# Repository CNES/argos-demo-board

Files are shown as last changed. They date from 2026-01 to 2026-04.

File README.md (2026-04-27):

# Argos Demo Board Using Arribada SMD Module

Demonstration and evaluation board designed to operate the **Arribada Argos SMD module** via USB and transmit **ARGOS uplink messages to the Kineis satellite constellation**.

---

> *© 2025/2026 CNES – Paul Miailhe.*  
> *This material is licensed under the CERN Open Hardware Licence Version 2 (CERN-OHL-S).*  
> *See licence: https://ohwr.org/licences/* 

> 
> 
> 
> 
> 
> 
---

<p align="center">
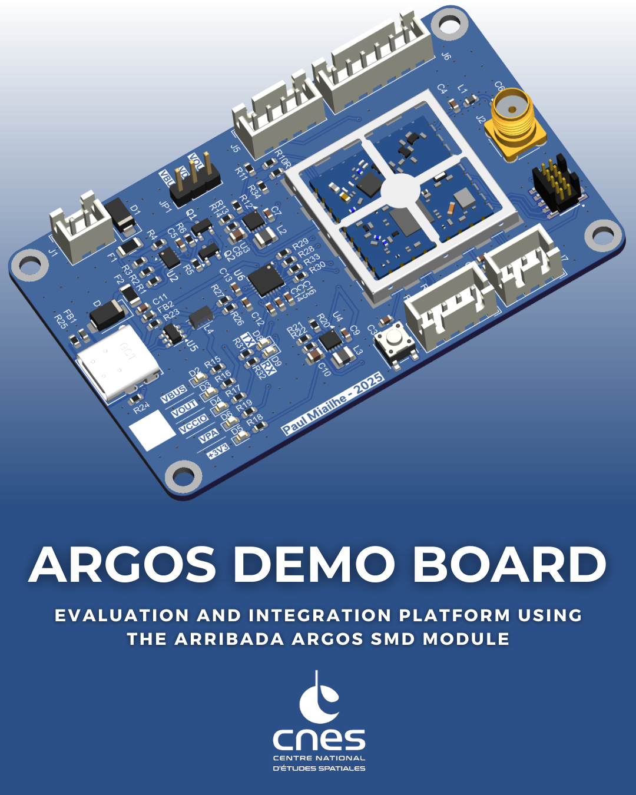
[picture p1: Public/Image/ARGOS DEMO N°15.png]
Argos Demonstration Board
  
</p>

---

## Introduction

This project presents an **Argos Transceiver Demonstration Board** intended for the evaluation, validation, and operation of the **Arribada Argos SMD module**.  
The board provides a compact and robust hardware platform to transmit **ARGOS uplink messages to the Kineis satellite constellation** using a standard **USB interface**.

Communication between the host computer and the Arribada SMD module is handled by a **FTDI FT231XQ USB-to-UART bridge**, directly interfacing with the module UART. This approach enables simple control of the transceiver using standard serial terminals or custom software tools.

The demonstration board integrates all essential functions required to operate the Arribada SMD module in a laboratory or development environment, including power supply conditioning, USB-to-UART communication, and RF interfacing. It is primarily intended to support early hardware validation, firmware development, and system-level testing of Argos communication chains prior to integration into a final embedded or avionics system.

This board targets engineers, students, and developers involved in **satellite communications, avionics, IoT, or space-related applications**, and may be used both as a standalone evaluation platform and as a reference hardware design.

---

> Inline with Arribada's open source philosophy, this board deliberately adopts a design distinct from the official demonstration hardware, focusing on simplicity and direct plug-and-play operation from a standard PC. The schematic and architecture are provided for reference, allowing potential users to reuse, adapt, or extend them according to their own needs..

---

## Hardware Design

<p align="center">
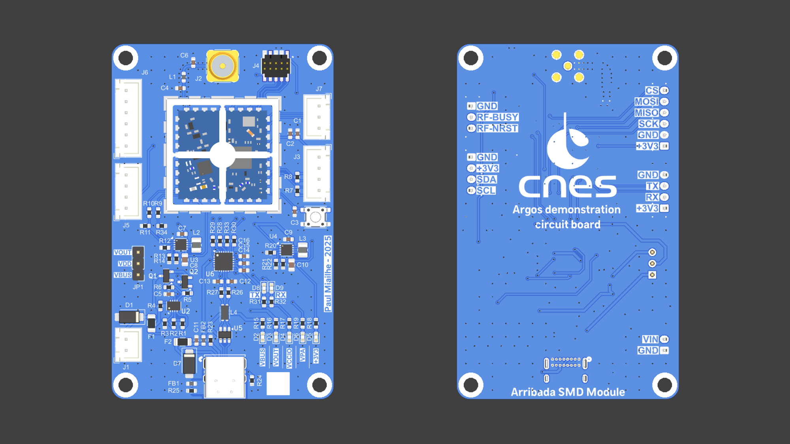
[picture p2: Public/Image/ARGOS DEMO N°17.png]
Top and bottom
  
</p>

### 1. Communication Architecture

Communication between the host PC and the **Arribada Argos SMD module** is performed through the module’s **UART interface**.  
This interface is used to send **AT commands** from a PC in order to configure the module and transmit **ARGOS uplink messages**. 
[→ See details on GitHub Arribada](https://github.com/arribada/argos-smd-at-kineis-firmware)

The USB-to-UART conversion is handled by a **FTDI FT231XQ USB 2.0 to UART bridge**. This device converts USB data received from a **virtual COM port** into UART signals fully compatible with the Arribada SMD module.

This architecture allows the board to be operated using:
- Standard serial terminal software
- Custom scripts
- Dedicated test or validation tools

No additional embedded controller is required, which simplifies early testing and debugging.

---

### 2. Power Supply Architecture

The card supports two power supply modes to suit different uses.

#### 2.1 Power Source Selection

Power source selection is performed using the **JP1 jumper**, which allows switching between:
- **VBUS → VDD (5V)** supplied by the **USB-C port**
- **VOUT → VDD (5V)** supplied via the **external power input on connector J1**

#### 2.2 External Power Protection

The external power input on **connector J1** is protected by:
- A **resettable PTC fuse 1206L050YR**
- A **LTC4365 protection circuit**

The **LTC4365** provides:
- **Reverse polarity protection**
- **Undervoltage protection** with a threshold set to **2.5 V**
- **Overvoltage protection** for input voltages exceeding **5 V**

#### 2.3 Power Regulation

After the protection stage, the power rail is distributed to two **TPS63900 buck-boost converters**:
- One converter supplies the **RF power amplifier (PA)** and is **enabled and controlled directly by the Arribada SMD module**
- The second converter is **always enabled** and provides the regulated **3.3 V supply** required for the **Arribada SMD module logic**

---

### 3. Connector Types

The Argos Demo Board uses the following connector families:

- **USB4085-GF-A (GCT)**  
  **USB Type-C receptacle (16-pin)** used for:
  - USB 2.0 communication with the host PC
  - Board power supply via **VBUS**

- **JST B2B-XH series**  
  **Through-hole wire-to-board connectors** used for:
  - External power input (**2.5 V to 5 V**)
  - Digital interfaces (**UART, SPI, GPIO – 3.3 V logic**)
  - General-purpose I/O connections

- **FTSH-105-01-L-DV-K (Samtec)**  
  **10-pin JTAG connector** used for:
  - Programming
  - Low-level debugging of the **Arribada Argos SMD module**
  - Access to **JTAG/SWD signals** of the embedded **STM32WL55**

- **60312002114503 (Würth Elektronik)**  
  **SMA 50 Ω RF connector** used for:
  - RF output connection
  - External antenna interface for the **ARGOS frequency band**
  - ⚠️ When transmitting, it is important to have at least a 50 Ohm load connected to the antenna output to protect against impedance mismatch. 

---

### 4. Functional Diagram

<p align="center">
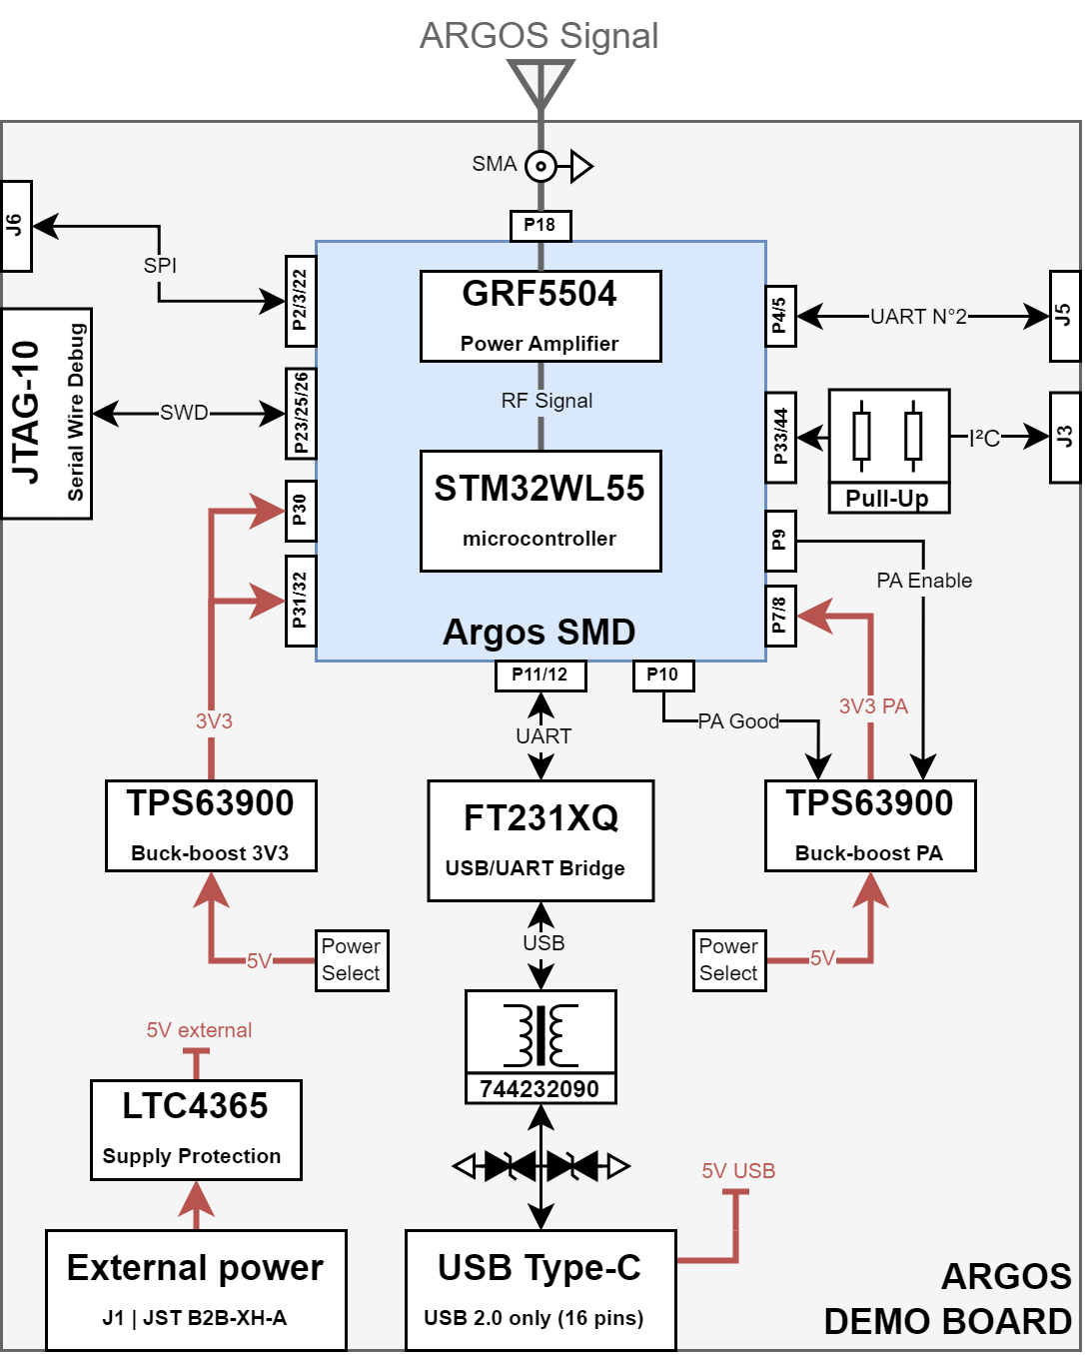
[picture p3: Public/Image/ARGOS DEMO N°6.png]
Argos Demonstration Board – Functional Diagram
  
</p>

---
## Summary of the Bill of Materials (BOM) 

  
Components used on the board, with their official datasheets:

| Reference | Part Number | Role / Function | Datasheet |
|---|---|---|---|
| D1, D7 | SMAJ15CA | TVS diode for surge and ESD protection | [→ Datasheet Littelfuse](https://www.littelfuse.com/assetdocs/tvs-diodes-smaj-datasheet?assetguid=13c2a823-03b8-4d1f-9ddc-9b44670aed9d) |
| F1, F2 | 1206L035/16YR | Resettable PTC fuse (overcurrent protection) | [→ Datasheet Littelfuse](https://www.littelfuse.com/assetdocs/resettable-ptcs-1206l-datasheet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) |
| FB1, FB2 | BLM18KG601SN1D | Ferrite bead for EMI suppression | [→ Datasheet Murata](https://pim.murata.com/en-eu/pim/details/?partNum=BLM18KG601SN1%23) |
| L4 | 744232090 | Common-mode choke for USB line filtering | [→ Datasheet Würth Elektronik](https://www.we-online.com/components/products/datasheet/744232090.pdf) |
| Q1, Q2 | BSN20 | N-channel MOSFET for switching and protection | [→ Datasheet DIODES INC.](http://www.diodes.com/assets/Datasheets/ds31898.pdf) |
| SW1 | PTS647 | Momentary tactile push button switch | [→ Datasheet C&K](https://www.ckswitches.com/media/1471/pts647.pdf) |
| U2 | LTC4365DDB | Overvoltage, undervoltage and reverse polarity protection IC | [→ Datasheet Analog Devices](https://www.analog.com/media/en/technical-documentation/data-sheets/4365fa.pdf) |
| U3, U4 | TPS63900 | Buck-boost DC/DC converters | [→ Datasheet Texas Instruments](https://www.ti.com/lit/ds/symlink/tps63900.pdf) |
| U5 | 82400102 | Low-capacitance TVS diode array for USB protection | [→ Datasheet Würth Elektronik](https://www.we-online.com/components/products/datasheet/82400102.pdf) |
| U6 | FT231XQ | USB-to-UART bridge | [→ Datasheet FTDI](https://www.ftdichip.com/Support/Documents/DataSheets/ICs/DS_FT231X.pdf) |
| H4 | 3610213126S | RF shielding cabinet | [→ Datasheet Würth Elektronik](https://www.we-online.com/catalog/datasheet/3610213126S.pdf) |
| J8 | USB4085-GF-A | USB 2.0-only 16P Type-C Receptacle connector | [→ Datasheet GCT](https://www.usb.org/sites/default/files/documents/usb_type-c.zip) |
| J2 | 60312002114503 | Coaxial connector SMA | [→ Datasheet Würth Elektronik](https://www.we-online.com/components/products/datasheet/60312002114503.pdf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) |
| J4 | FTSH-105-01-L-DV-K | JTAG 10-PINS | [→ Datasheet Samtec](https://suddendocs.samtec.com/catalog_english/ftsh_smt.pdf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) |
| J1, J3, J5, J6, J7 | B2B-XH | Through-hole wire-to-board connectors | [→ Datasheet JST](https://www.jst.fr/core/file.get?path=doc/jst/family/pdf/exh0125.pdf) |
| U1 | Argos SMD module | Transceiver Argos SMD for uplink Argos satellite | [→ Datasheet Arribada](https://github.com/arribada/featherwings-argos-smd-hw/wiki) |

---

## Getting Started

1. Connect the demonstration board to a host computer using a USB cable.
2. Install the **FTDI drivers** if required.
3. Select the desired **power input** using the **JP1 jumper**.
4. Connect an **antenna or a 50 Ω RF load** to the **SMA connector** before powering the board.
5. Open a **serial terminal** or a **custom software tool** on the host computer.
6. Configure the serial port according to the **Arribada Argos SMD module specifications**.
7. Send **AT commands** to configure the module and transmit **ARGOS uplink messages**.
8. If the board is operating correctly, the **5 V and 3.3 V LEDs** should be ON, and **TX/RX activity LEDs** should indicate serial communication.

Refer to the Arribada SMD module documentation for command syntax and operational details.

---

## Regulatory and Operational Notice

ARGOS transmissions are subject to regulatory constraints and operational authorization.

- Transmission over the ARGOS / Kineis constellation may require prior approval
- Users are responsible for ensuring compliance with applicable regulations
- This board does not grant any transmission rights by itself

---

## Mechanical Characteristics

- Dimensions: **80 × 50 mm**
- Maximum thickness: **13.5 mm**
- Mounting holes: 4 × Ø3.2 mm
- Weight without bracket: ** g**
- **STEP 3D** file available here:

<p align="center">
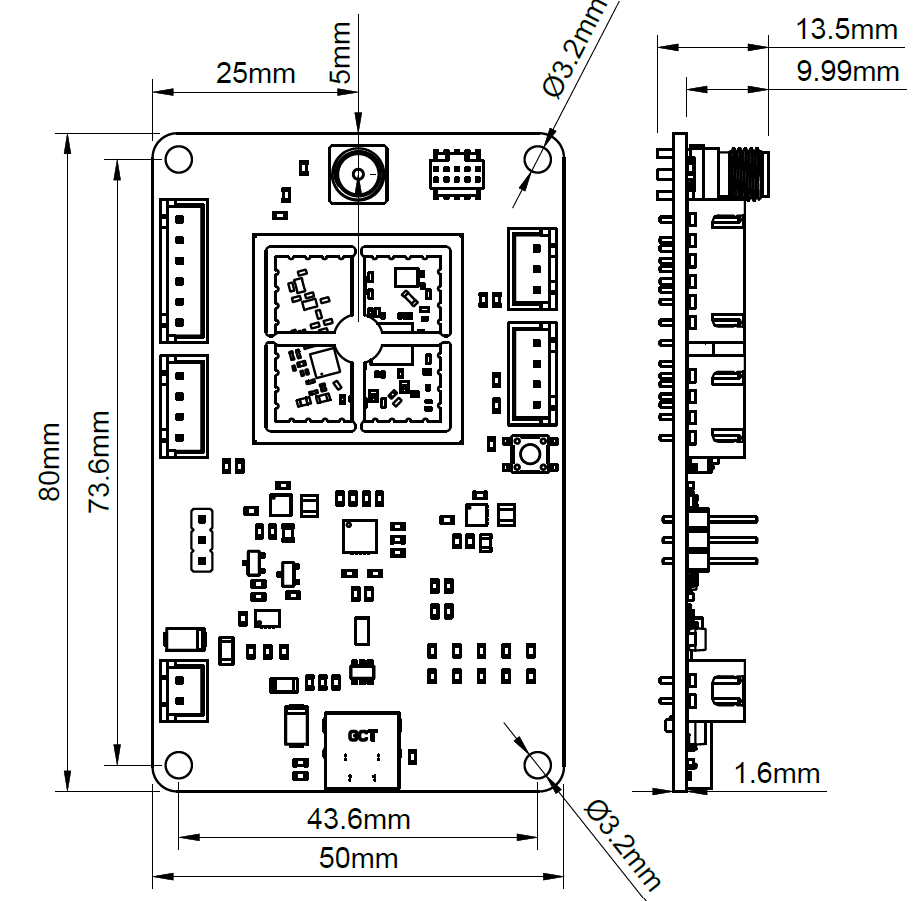
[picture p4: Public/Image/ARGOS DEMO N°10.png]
Argos Demonstration Board – Mechanical Characteristics
  
</p>

---

## Regulatory and Operational Notice

ARGOS transmissions are subject to regulatory and operational constraints.

- Transmission over the ARGOS / Kineis constellation require prior authorization
- Users are responsible for regulatory compliance
- This board does **not** grant transmission rights by itself

---

## References & Resources

- **Arribada Initiative** – Official site  
  See link: <https://arribada.org>

- **Official Argos SMD Arduino Demo** – by Arribada  
  The full Arduino-based demonstration for the Argos SMD module is available on GitHub.  
  See link: <https://github.com/arribada/argos-smd-test-arduino>

- **Official Breakout Board FeatherWings** – by Arribada  
  This breakout board can be used with a Feather board (from Adafruit) to connect the ARGOS-SMD module.  
  It exposes the ARGOS-SMD module pins to the Feather board and includes a dedicated LDO to power the RF amplifier.  
  See link: <https://github.com/arribada/featherwings-argos-smd-hw>

- **Official Argos SMD Hardware Module** – by Arribada  
  The Arribada Argos SMD module is a compact **20 × 20 mm PCB** designed to operate as a standalone module or co-processor, enabling satellite communication via the **Kineis network**.  
  See link: <https://github.com/arribada/argos-smd-hw>

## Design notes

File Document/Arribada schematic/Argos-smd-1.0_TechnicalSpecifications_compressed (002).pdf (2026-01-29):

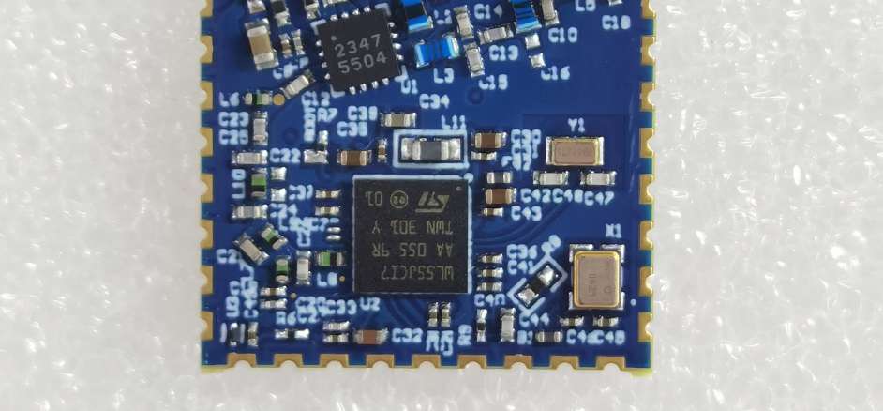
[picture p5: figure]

# SMD Module for Argos Communication

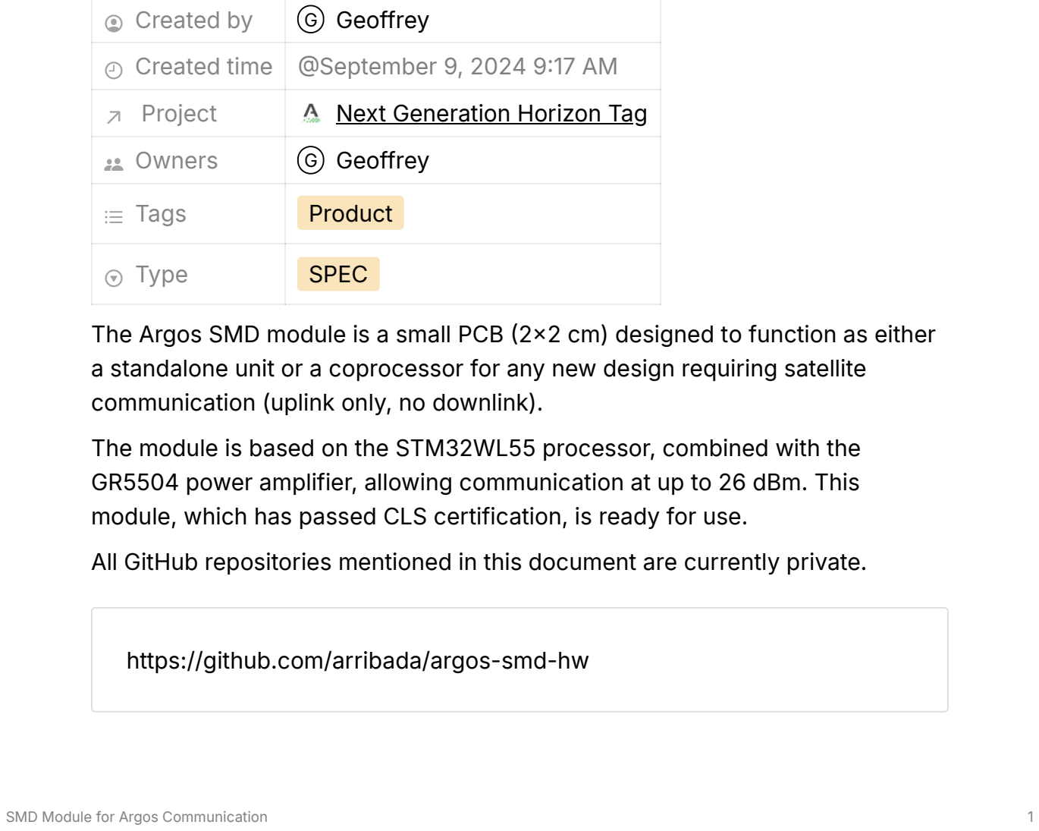
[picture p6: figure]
SMD Module for Argos Communication; Created by; G Geoffrey; Created time; Project; Next Generation Horizon Tag (https://www.notion.so/Next-Generation-Horizon-Tag-afd0edbfa5694a8ea1d60a53f880d056?pvs=21); Owners; Tags; Product; Type; SPEC; communication (uplink only, no downlink).; https://github.com/arribada/argos-smd-hw; September 9, 2024 9

The Argos SMD module is a small PCB (2x2 cm) designed to function as either a standalone unit or a coprocessor for any new design requiring satellite

The module is based on the STM32WL55 processor, combined with the GR5504 power amplifier, allowing communication at up to 26 dBm. This module, which has passed CLS certification, is ready for use.
All GitHub repositories mentioned in this document are currently private.

# 1. Size and Dimensions

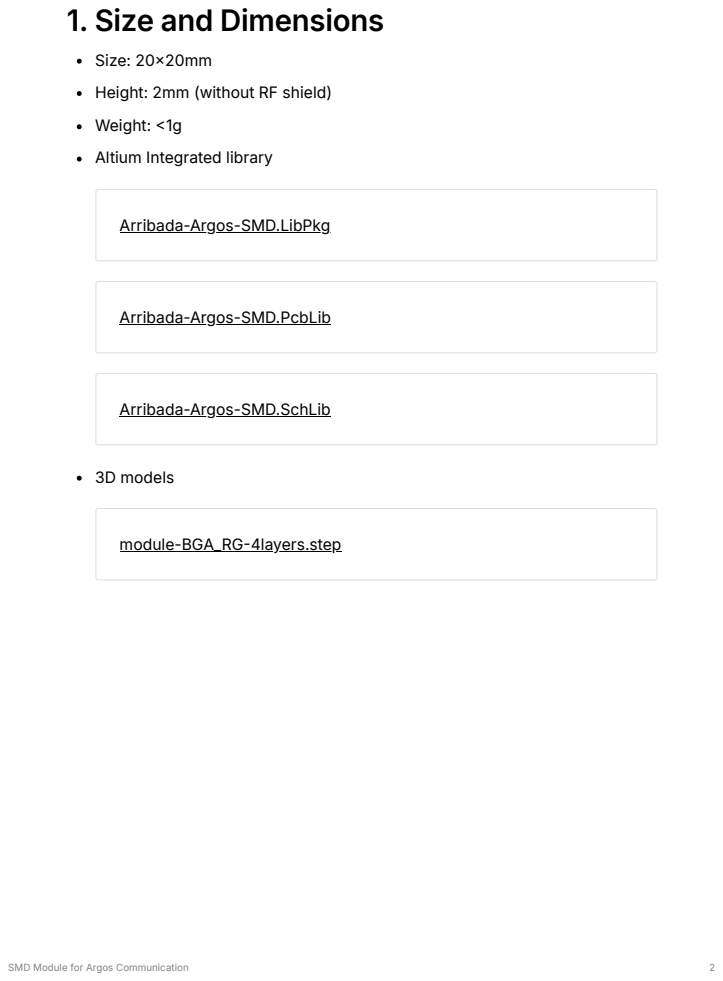
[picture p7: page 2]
3D models; module-BGA_RG-4layers.step

Size: 20x20mm
Height: 2mm (without RF shield)
Weight: <1g
Altium Integrated library

Arribada-Argos-SMD.LibPkg (https://www.notion.so/signed/https%3A%2F%2Fprod-files-secure.s3.us-west-2.amazonaws.com%2Ffb6dcbe8-5387-40b2-9784-804645a3e60e%2F554a35c8-f4b7-4a3d-868e-001f1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)

Arribada-Argos-SMD.PcbLib (https://www.notion.so/signed/https%3A%2F%2Fprod-files-secure.s3.us-west-2.amazonaws.com%2Ffb6dcbe8-5387-40b2-9784-804645a3e60e%2Fce79ae03-3859-4164-9c10-c49fd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)

Arribada-Argos-SMD.SchLib (https://www.notion.so/signed/https%3A%2F%2Fprod-files-secure.s3.us-west-2.amazonaws.com%2Ffb6dcbe8-5387-40b2-9784-804645a3e60e%2Ff151bbcf-b28b-4e5a-810b-bd9d2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)

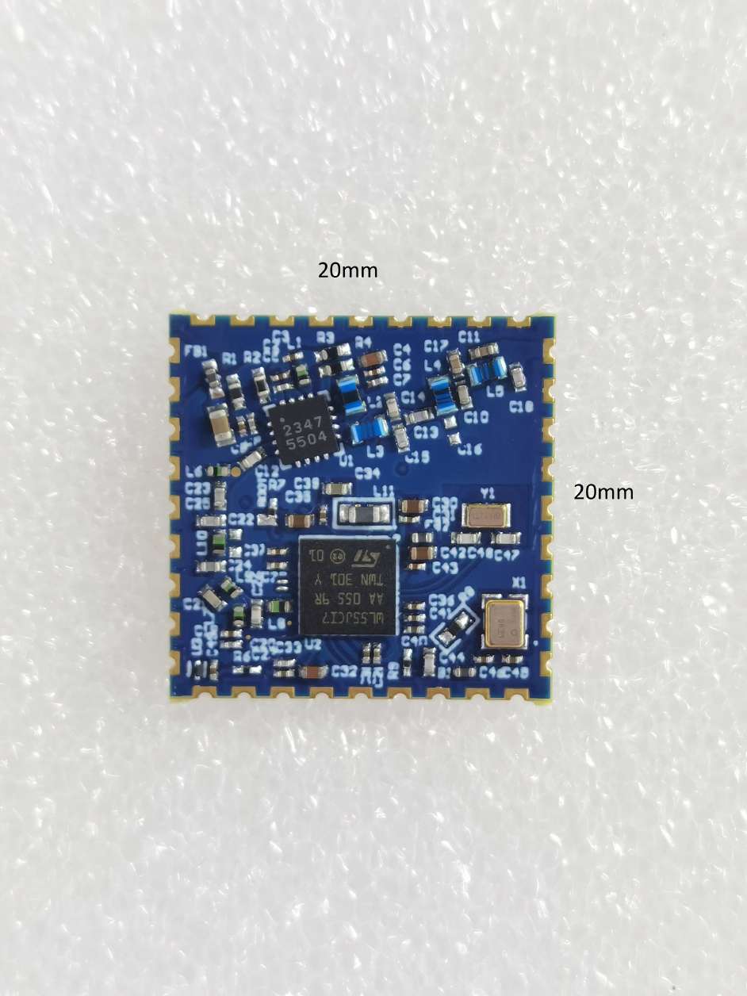
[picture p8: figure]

It’s possible to add an RF shield (https://www.mouser.fr/ProductDetail/Wurth-Elektronik/36903255S?qs=ECv811tYSNg3zTXFceofhw%3D%3D) on the board dedicated to integrated the SMD module with the following dimensions:

Size: 25x25mm

Height: 3.2mm

# 2. Integration

The module integration requires a power supply for the STM32 and a second one for the external power amplifier. A PI-filter should be added to the antenna output before connecting it to the antenna connector. The TPS63901 (https://www.ti.com/product/TPS63901) is recommended for powering the external PA.
A breakout board is available to test the module and provide a design integration example. This breakout board can be used with a Feather board (from Adafruit) to connect the ARGOS-SMD module. It exposes the ARGOS-SMD module pins to the Feather board and includes a dedicated LDO to power the RF amplifier. You can find resources at the following link.

# 3 - Power Supply Voltages

VDD (Core Supply Voltage):
1.8V to 3.6V operating range.

Typical operation at 3.3V.
VBAT (Battery Backup Supply):

Backup battery voltage range from 1.55V to 3.6V.

This is used to power the RTC (Real-Time Clock), backup registers, and some other low-power functionalities when the main supply is off. VDDPA (Power Amplifier Supply):

For the internal power amplifier (PA) dedicated to the radio subsystem. 1.8V to 3.6V supply voltage.

VDD_EXTPA (Power External Amplifier):

Typical operation at 3.3V.

Argos communication power consumption: TX power: 25.8dBm (380mW)

VPA: 3.40V
Power max: 292.40mA

Power mean: 165.13mA

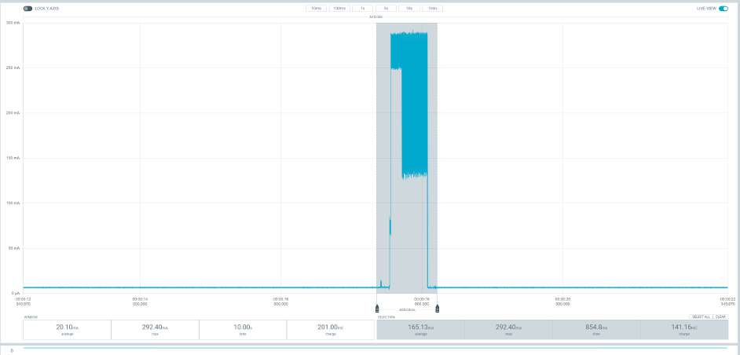
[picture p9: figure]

# 4. Pinout

The module features the following pinout configuration:
While it is possible to adapt the pinout definition through programming of the STM32 module, the following pinout has been selected.

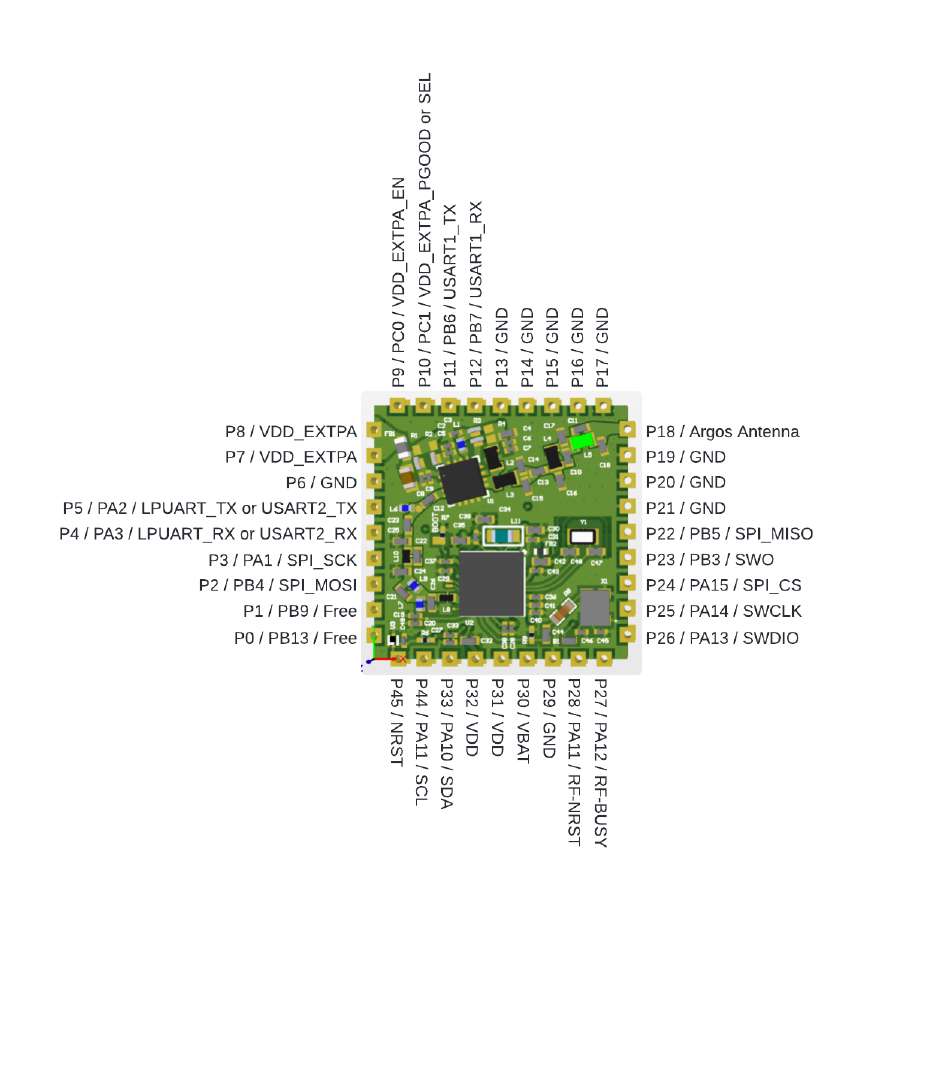
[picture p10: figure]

System:
P35 => nRST

P31 => VDD

P32 => VDD
P30 => VBAT

Power amplifier:
P7: VDD power amplifier

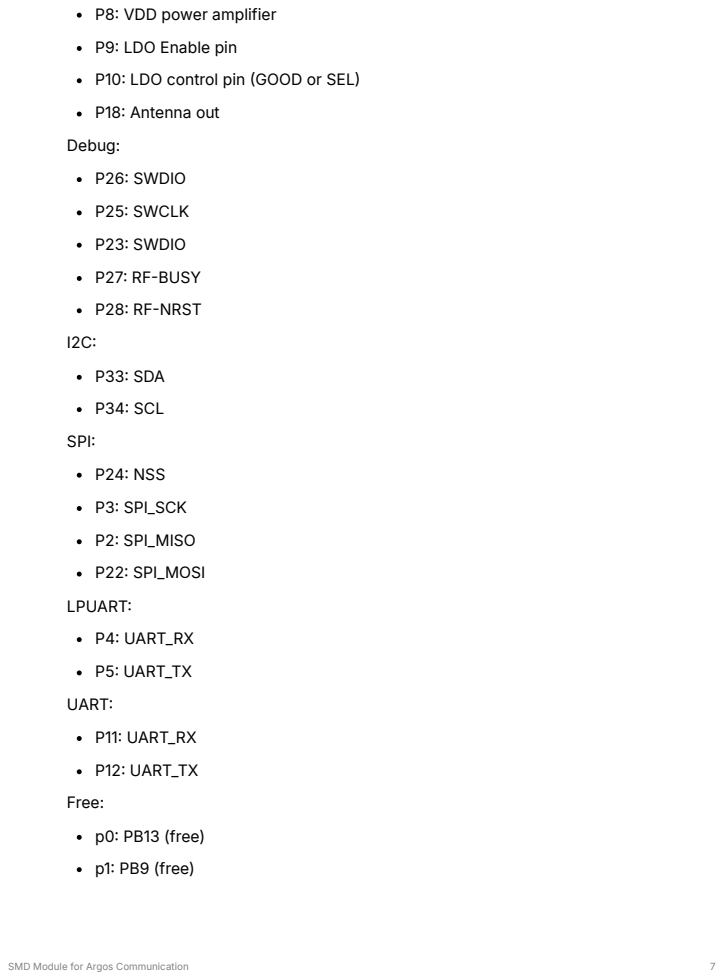
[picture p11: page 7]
P8: VDD power amplifier; P9: LDO Enable pin; P10: LDO control pin (GOOD or SEL); P18: Antenna out; Debug:; P26: SWDIO; P25: SWCLK; P23: SWDIO; P27: RF-BUSY; P28: RF-NRST; P33: SDA; P34: SCL; SPI:; P24: NSS; P3: SPI_SCK; P2: SPI_MISO; P22: SPI_MOSI; LPUART:; P4: UART_RX; P5: UART_TX; UART:; P11: UART_RX; P12: UART_TX; Free:; p0: PB13 (free); p1: PB9 (free)

# 4. Software

The firmware used for the module is based on the latest CLS firmware v6.2.1 and is available on the following GitHub repository.

https://github.com/arribada/SMD-AT-Kineis
The Kineis stack requires credentials (ID, address, secret key) to run properly. The easiest way to test the module is to use the latest KimGUI interface provided by CLS. This computer application allows communication with the module via UART.
A Zephyr driver can also be used to communicate with the SMD module. For example, when combining the breakout board with an Adafruit Feather board, the following Zephyr driver can be used to test the module.

It is also possible to use the STM32 example for AT commands to control the Sub-GHz module at this link:

https://github.com/arribada/SMD_AT_Slave

## 4.1. Communication Protocol

The SMD module is configured to communicate via LPUART1 with the following parameters:
Baud Rate: 9600 bps

Data Bits: 8

Stop Bits: 1
Parity: None

Flow Control: None

## 4.2. Command Structure

An ID provides by CLS should be configured on the SMD module to allows communication (28 or 32bits ID).
The SMD module use the same KimGUI AT command format, like this :

AT+[COMMAND]=[PARAMETER]

Example commands:
"AT+PING=?\r\n to get information

"AT+TX=<user_data>\r\n to set information

List of commands:

{ "AT+VERSION", | 10, bMGR_AT_CMD_VERSION_cmd},
{ "AT+PING", | 7, bMGR_AT_CMD_PING_cmd},
{ "AT+FW", | 5, bMGR_AT_CMD_FW_cmd},
{ "AT+ADDR", | 7, bMGR_AT_CMD_ADDR_cmd},
{ "AT+ID", | 5, bMGR_AT_CMD_ID_cmd},
{ "AT+SN", | 5, bMGR_AT_CMD_SN_cmd},
{ "AT+RCONF", | 8, bMGR_AT_CMD_RCONF_cmd},
{ "AT+SAVE_RCONF", | 13, bMGR_AT_CMD_SAVE_RCONF_cmd},
{ "AT+LPM", | 6, bMGR_AT_CMD_LPM_cmd},
{ "AT+TX", | 5, bMGR_AT_CMD_TX_cmd},
{ "AT+CW", | 5, bMGR_AT_CMD_CW_cmd},
{ "AT+PREPASS_EN", | 13, bMGR_AT_CMD_PREPASS_EN_cmd},
{ "AT+UDATE", | 8, bMGR_AT_CMD_UDATE_cmd},
{ "AT+ATXRP", | 8, bMGR_AT_CMD_ATXRP_cmd},

# 5. Environmental Specifications

The hardware components used in this design have been selected to meet rigorous environmental requirements, ensuring reliable operation in a wide range of conditions. The key specifications are as follows:
1. Operating Temperature Range:

The components are capable of operating in temperatures ranging from 40°C to +85°C.

2. Storage Temperature:
The hardware can be safely stored in environments with temperatures between 55°C and +150°C.
3. Humidity Resistance:
Operation in environments with up to 85% to 95% relative humidity
4. Moisture Sensitivity:

All components are Moisture Sensitivity Level (MSL 1).
5. RoHS Compliance:

All components are RoHS compliant.
This hardware design leverages industry-standard components, known for their reliability and performance in demanding environments, making it ideal for robust applications such as satellite communication systems.

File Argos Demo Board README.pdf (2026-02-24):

README.md | 2026-01-30

# Argos Demo Board Using Arribada SMD Module

Demonstration and evaluation board designed to operate the Arribada Argos SMD module via USB and transmit ARGOS uplink messages to the Kineis satellite constellation.

© 2025/2026 CNES – Paul Miailhe.
This material is licensed under the CERN Open Hardware Licence Version 2 (CERN-OHL-S). See licence: https://ohwr.org/licences/


## Introduction

This project presents an Argos Transceiver Demonstration Board intended for the evaluation, validation, and operation of the Arribada Argos SMD module.

The board provides a compact and robust hardware platform to transmit ARGOS uplink messages to the Kineis satellite constellation using a standard USB interface.

Communication between the host computer and the Arribada SMD module is handled by a FTDI FT231XQ USB-to-UART bridge, directly interfacing with the module UART. This approach enables simple control of the transceiver using standard serial terminals or custom software tools.

The demonstration board integrates all essential functions required to operate the Arribada SMD module in a laboratory or development environment, including power supply conditioning, USB-to-UART communication, and RF interfacing. It is primarily intended to support early hardware validation, firmware development, and system-level testing of Argos communication chains prior to integration into a final embedded or avionics system.

This board targets engineers, students, and developers involved in satellite communications, avionics, IoT, or space-related applications, and may be used both as a standalone evaluation platform and as a reference hardware design.

Inline with Arribada's open source philosophy, this board deliberately adopts a design distinct from the official demonstration hardware, focusing on simplicity and direct plug-and-play operation from a standard PC. The schematic and architecture are provided for reference, allowing potential users to reuse, adapt, or extend them according to their own needs..

## Hardware Design

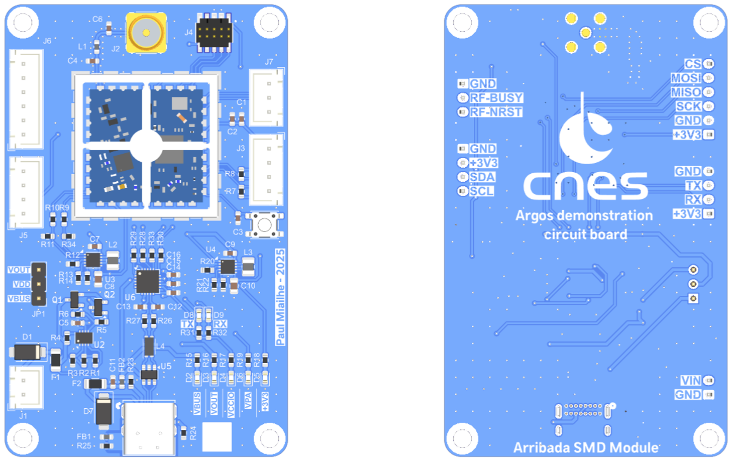
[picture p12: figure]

1. Communication Architecture

Communication between the host PC and the Arribada Argos SMD module is performed through the module’s UART interface.
This interface is used to send AT commands from a PC in order to configure the module and transmit ARGOS uplink messages. → See details on GitHub Arribada (https://github.com/arribada/argos-smd-at-kineis-firmware)

The USB-to-UART conversion is handled by a FTDI FT231XQ USB 2.0 to UART bridge. This device converts USB data received from a virtual COM port into UART signals fully compatible with the Arribada SMD

module.

This architecture allows the board to be operated using:

Standard serial terminal software
Custom scripts
Dedicated test or validation tools

No additional embedded controller is required, which simplifies early testing and debugging.

2. Power Supply Architecture

The card supports two power supply modes to suit different uses.

### 2.1 Power Source Selection

Power source selection is performed using the JP1 jumper, which allows switching between:

VBUS → VDD (5V) supplied by the USB-C port
VOUT → VDD (5V) supplied via the external power input on connector J1

### 2.2 External Power Protection

The external power input on connector J1 is protected by:

A resettable PTC fuse 1206L050YR
A LTC4365 protection circuit

The LTC4365 provides:

Reverse polarity protection
Undervoltage protection with a threshold set to 2.5 V Overvoltage protection for input voltages exceeding 5 V

### 2.3 Power Regulation

After the protection stage, the power rail is distributed to two TPS63900 buck-boost converters:

One converter supplies the RF power amplifier (PA) and is enabled and controlled directly by the Arribada SMD module
The second converter is always enabled and provides the regulated 3.3 V supply required for the Arribada SMD module logic
3. Connector Types

The Argos Demo Board uses the following connector families:

USB4085-GF-A (GCT)
USB Type-C receptacle (16-pin) used for:

USB 2.0 communication with the host PC Board power supply via VBUS

JST B2B-XH series
Through-hole wire-to-board connectors used for:

External power input (2.5 V to 5 V)
Digital interfaces (UART, SPI, GPIO – 3.3 V logic) General-purpose I/O connections

FTSH-105-01-L-DV-K (Samtec)
10-pin JTAG connector used for:

Programming
Low-level debugging of the Arribada Argos SMD module Access to JTAG/SWD signals of the embedded STM32WL55

60312002114503 (Würth Elektronik)
SMA 50 Ω RF connector used for:

RF output connection
External antenna interface for the ARGOS frequency band
⚠ When transmitting, it is important to have at least a 50 Ohm load connected to the antenna output to protect against impedance mismatch.
4. Functional Diagram

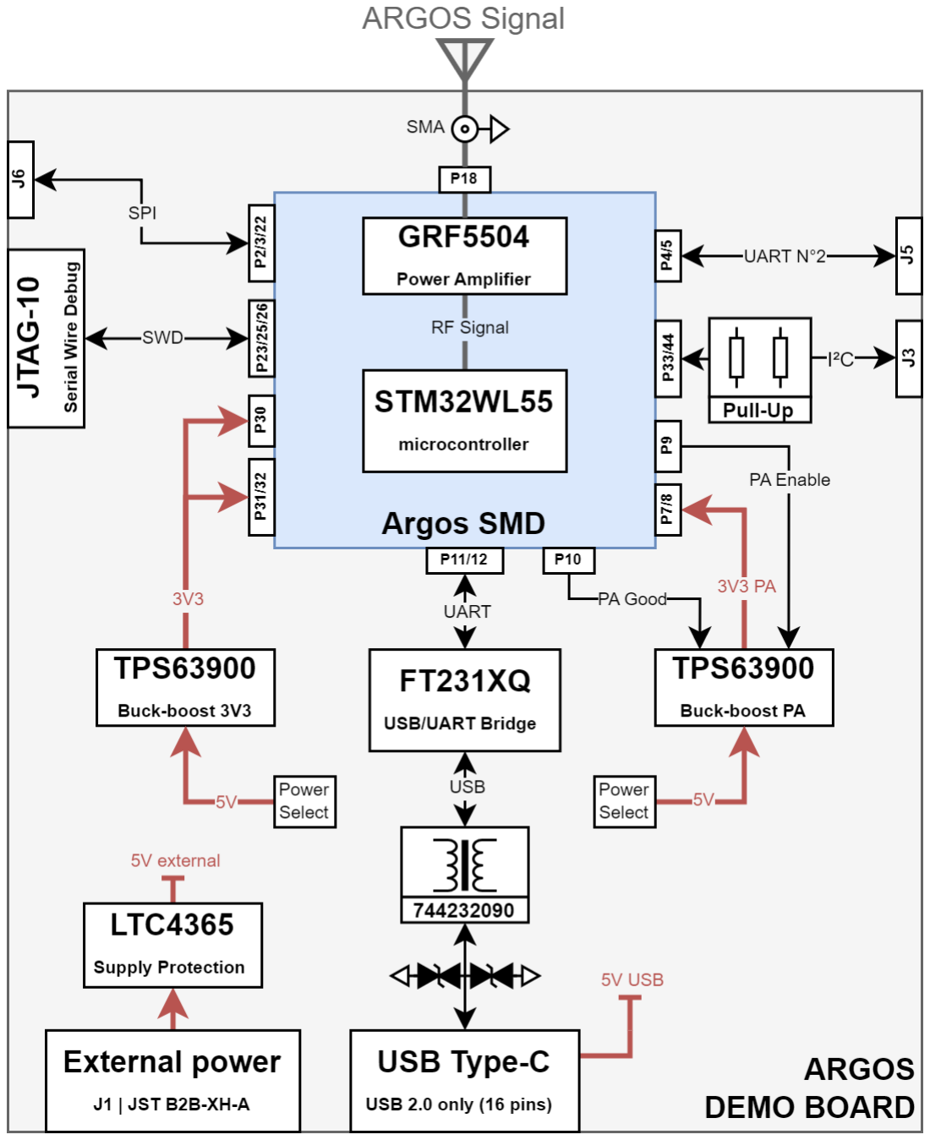
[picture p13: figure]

## Summary of the Bill of Materials (BOM)

Components used on the board, with their official datasheets:

Reference Part Number | Role / Function | Datasheet
D1, D7 | SMAJ15CA | TVS diode for surge and ESD protection | → Datasheet Littelfuse (https://www.littelfuse.com/assetdocs/tvs-diodes-smaj-datasheet?assetguid=13c2a823-03b8-4d1f-9ddc-9b44670aed9d)
F1, F2 | 1206L035/16YR | Resettable PTC fuse (overcurrent protection) | → Datasheet Littelfuse (https://www.littelfuse.com/assetdocs/resettable-ptcs-1206l-datasheet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)
FB1, FB2 | BLM18KG601SN1D Ferrite bead for EMI suppression | → Datasheet Murata (https://pim.murata.com/en-eu/pim/details/?partNum=BLM18KG601SN1%23)
L4 | 744232090 | Common-mode choke for USB line filtering | → Datasheet Würth Elektronik (https://www.we-online.com/components/products/datasheet/744232090.pdf)
Q1, Q2 | BSN20 | N-channel MOSFET for switching and protection | → Datasheet DIODES INC. (http://www.diodes.com/assets/Datasheets/ds31898.pdf)
SW1 | PTS647 | Momentary tactile push button switch | → Datasheet C&K (https://www.ckswitches.com/media/1471/pts647.pdf)

Reference Part Number | Role / Function | Datasheet
U2 | LTC4365DDB | Overvoltage, undervoltage and reverse polarity protection IC | → Datasheet Analog Devices (https://www.analog.com/media/en/technical-documentation/data-sheets/4365fa.pdf)
U3, U4 | TPS63900 | Buck-boost DC/DC converters | → Datasheet Texas Instruments (https://www.ti.com/lit/ds/symlink/tps63900.pdf)
U5 | 82400102 | Low-capacitance TVS diode array for USB protection | → Datasheet Würth Elektronik (https://www.we-online.com/components/products/datasheet/82400102.pdf)
U6 | FT231XQ | USB-to-UART bridge | → Datasheet FTDI (https://www.ftdichip.com/Support/Documents/DataSheets/ICs/DS_FT231X.pdf)
H4 | 3610213126S | RF shielding cabinet | → Datasheet Würth Elektronik (https://www.we-online.com/catalog/datasheet/3610213126S.pdf)
J8 | USB4085-GF-A | USB 2.0-only 16P Type-C Receptacle connector | → Datasheet GCT (https://www.usb.org/sites/default/files/documents/usb_type-c.zip)
J2 | 60312002114503 | Coaxial connector SMA | → Datasheet Würth Elektronik (https://www.we-online.com/components/products/datasheet/60312002114503.pdf)
J4 | FTSH-105-01-L- DV-K | JTAG 10-PINS | → Datasheet Samtec (https://suddendocs.samtec.com/catalog_english/ftsh_smt.pdf)
J1, J3, J5, J6, J7 | B2B-XH | Through-hole wire-to-board connectors | → Datasheet JST (https://www.jst.fr/core/file.get?path=doc/jst/family/pdf/exh0125.pdf)
U1 | Argos SMD module | Transceiver Argos SMD for uplink Argos satellite | → Datasheet Arribada (https://github.com/arribada/featherwings-argos-smd-hw/wiki)

## Getting Started

1. Connect the demonstration board to a host computer using a USB cable.
2. Install the FTDI drivers if required.
3. Select the desired power input using the JP1 jumper.
4. Connect an antenna or a 50 Ω RF load to the SMA connector before powering the board.
5. Open a serial terminal or a custom software tool on the host computer.
6. Configure the serial port according to the Arribada Argos SMD module specifications.
7. Send AT commands to configure the module and transmit ARGOS uplink messages.
8. If the board is operating correctly, the 5 V and 3.3 V LEDs should be ON, and TX/RX activity LEDs should indicate serial communication.

Refer to the Arribada SMD module documentation for command syntax and operational details.

## Regulatory and Operational Notice

ARGOS transmissions are subject to regulatory constraints and operational authorization.

Transmission over the ARGOS / Kineis constellation may require prior approval Users are responsible for ensuring compliance with applicable regulations

This board does not grant any transmission rights by itself

## Mechanical Characteristics

Dimensions: 80 × 50 mm
Maximum thickness: 13.5 mm Mounting holes: 4 × Ø3.2 mm Weight without bracket: ** g**
STEP 3D file available here:


## Regulatory and Operational Notice

ARGOS transmissions are subject to regulatory and operational constraints.

Transmission over the ARGOS / Kineis constellation require prior authorization Users are responsible for regulatory compliance
This board does not grant transmission rights by itself

## References & Resources

Arribada Initiative – Official site See link: https://arribada.org

Official Argos SMD Arduino Demo – by Arribada
The full Arduino-based demonstration for the Argos SMD module is available on GitHub.
See link: https://github.com/arribada/argos-smd-test-arduino

Official Breakout Board FeatherWings – by Arribada
This breakout board can be used with a Feather board (from Adafruit) to connect the ARGOS-SMD module.
It exposes the ARGOS-SMD module pins to the Feather board and includes a dedicated LDO to power the RF amplifier.
See link: https://github.com/arribada/featherwings-argos-smd-hw

Official Argos SMD Hardware Module – by Arribada
The Arribada Argos SMD module is a compact 20 × 20 mm PCB designed to operate as a standalone module or co-processor, enabling satellite communication via the Kineis network.
See link: https://github.com/arribada/argos-smd-hw

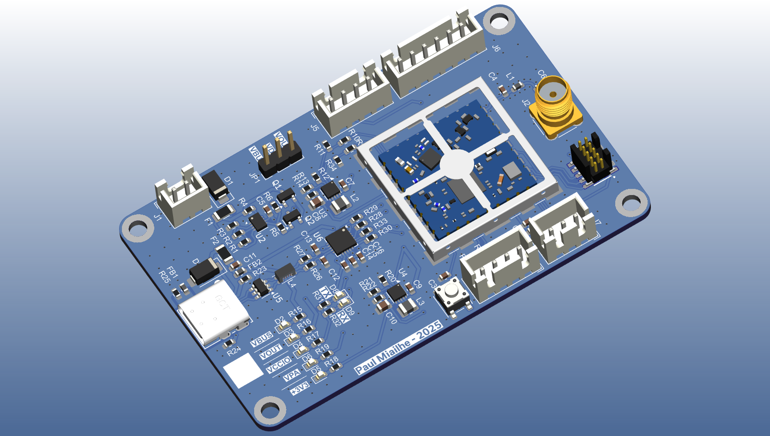
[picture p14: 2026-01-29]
Public/Image/ARGOS DEMO N°13.png

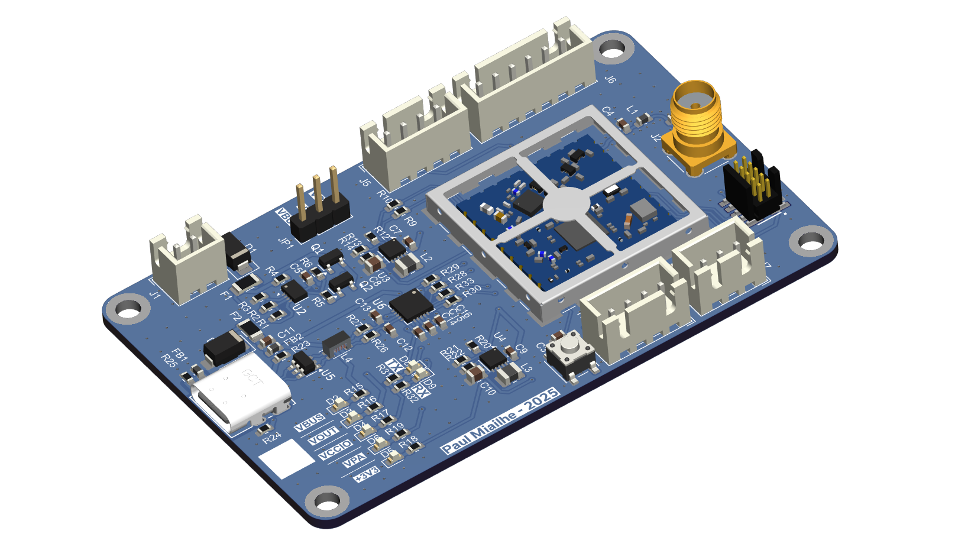
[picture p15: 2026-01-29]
Public/Image/ARGOS DEMO N°1.png

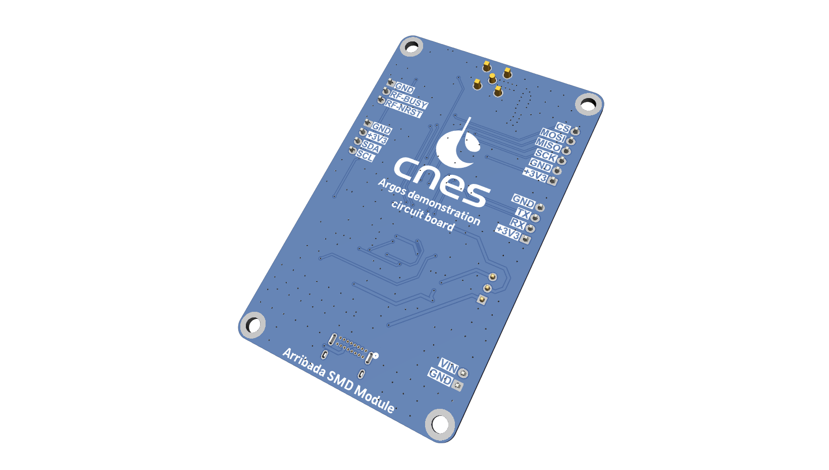
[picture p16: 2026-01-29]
Public/Image/ARGOS DEMO N°8.png

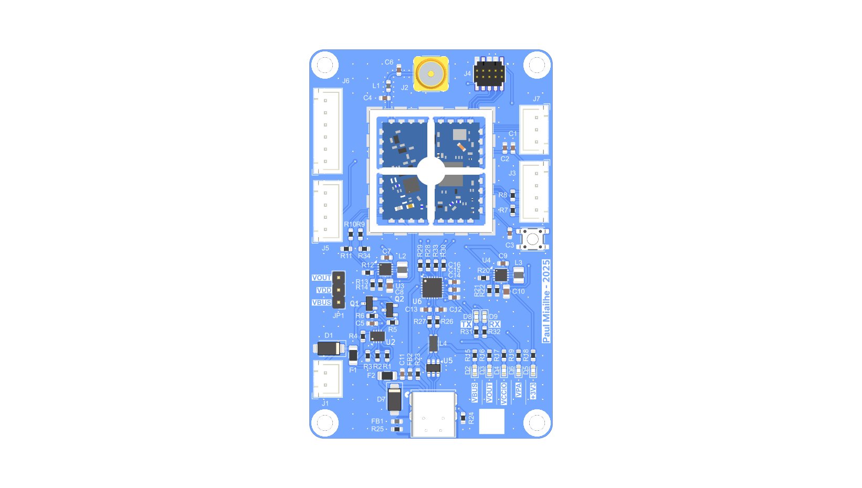
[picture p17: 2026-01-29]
Public/Image/ARGOS DEMO N°3.png

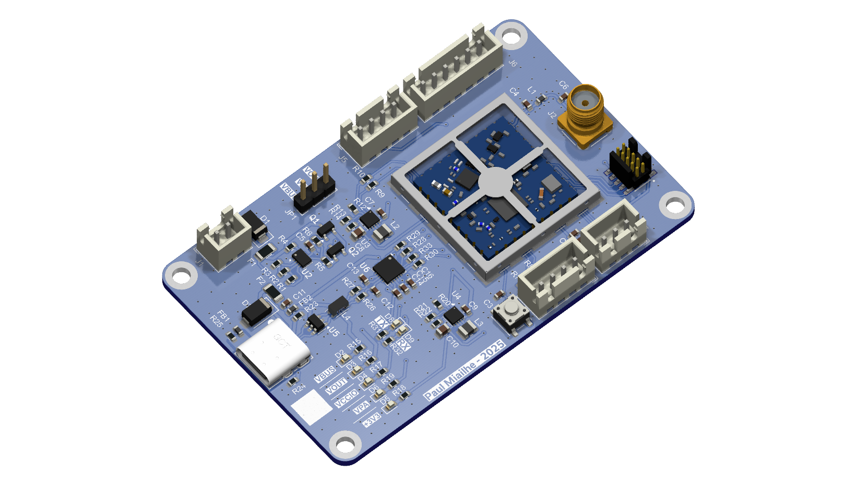
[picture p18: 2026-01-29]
Public/Image/ARGOS DEMO N°9.png

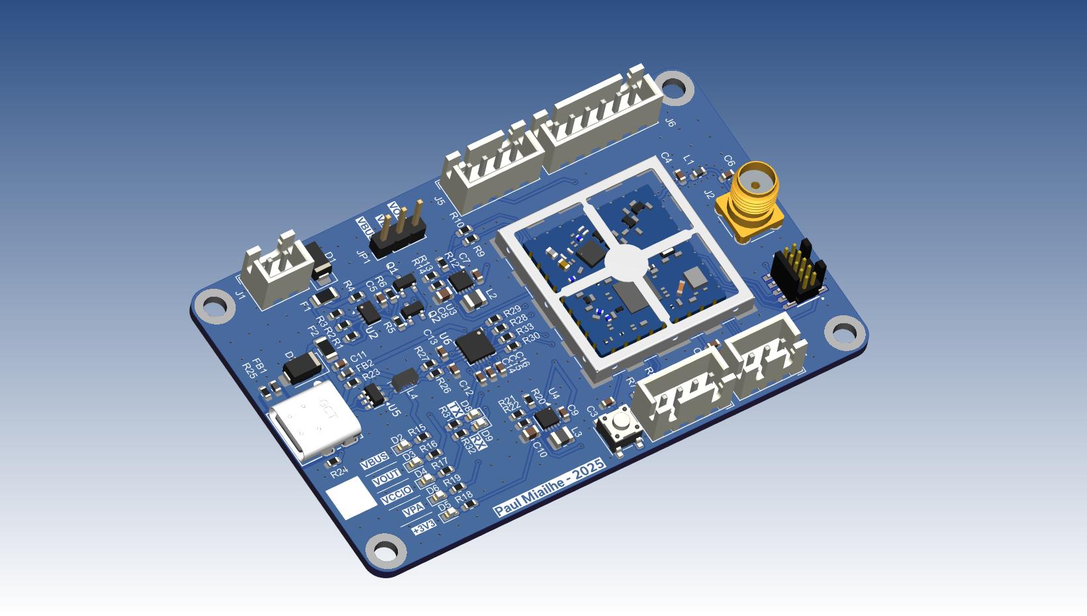
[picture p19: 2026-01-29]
Public/Image/ARGOS DEMO N°12.jpg

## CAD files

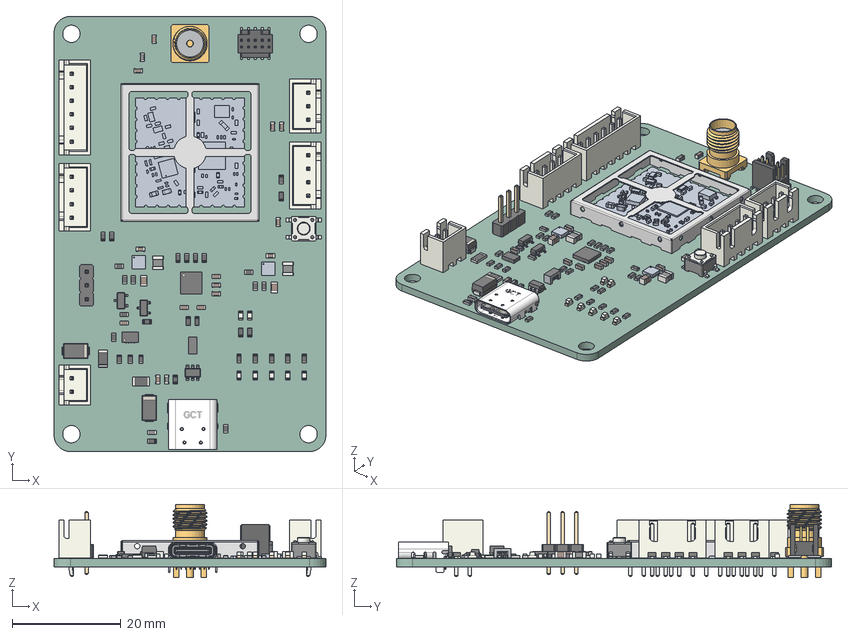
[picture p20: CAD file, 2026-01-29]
ARGOS DEMO.step
50.0 x 80.0 x 13.5 mm
H_Wurth_WE-SHC-SMT-FRAME_36103255S
Fuse_1206_3216Metric x 2
R_0603_1608Metric x 32
C_0603_1608Metric x 14
LED_0603_1608Metric x 7
60312002114503 (rev1)
SW_SPST_PTS647Sx38
JST_XH_B4B-XH-A_1x04_P2.50mm_Vertical x 2
L_Wurth_WE-CNSW-1206
SOT-23 x 2
C_0805_2012Metric x 2
JST_XH_B6B-XH-A_1x06_P2.50mm_Vertical
L_0603_1608Metric x 3
FTSH-105-01-L-DV-K_body
FTSH-105-01-L-DV-K_pins1
FTSH-105-01-L-DV-K_pins2
L_1008_2520Metric x 2
QFN-20-1EP_4x4mm_P0.5mm_EP2.5x2.5mm
JST_XH_B2B-XH-A_1x02_P2.50mm_Vertical
D_SMA x 2
ARGOS DEMO 1.70.1
ARGOS DEMO 1.70.2
ARGOS DEMO 1.70.3
ARGOS DEMO 1.70.4
ARGOS DEMO 1.70.5
ARGOS DEMO 1.70.6
ARGOS DEMO 1.70.7
ARGOS DEMO 1.70.8
ARGOS DEMO 1.70.9
ARGOS DEMO 1.70.10
ARGOS DEMO 1.70.11
ARGOS DEMO 1.70.12
ARGOS DEMO 1.70.13
ARGOS DEMO 1.70.14
ARGOS DEMO 1.70.15
ARGOS DEMO 1.70.16
ARGOS DEMO 1.70.17
ARGOS DEMO 1.70.18
ARGOS DEMO 1.70.19
ARGOS DEMO 1.70.20
ARGOS DEMO 1.70.21
ARGOS DEMO 1.70.22
ARGOS DEMO 1.70.23
ARGOS DEMO 1.70.24
ARGOS DEMO 1.70.25
ARGOS DEMO 1.70.26
ARGOS DEMO 1.70.27
ARGOS DEMO 1.70.28
ARGOS DEMO 1.70.29
ARGOS DEMO 1.70.30
ARGOS DEMO 1.70.31
ARGOS DEMO 1.70.32
ARGOS DEMO 1.70.33
ARGOS DEMO 1.70.34
ARGOS DEMO 1.70.35
ARGOS DEMO 1.70.36
ARGOS DEMO 1.70.37
ARGOS DEMO 1.70.38
ARGOS DEMO 1.70.39
ARGOS DEMO 1.70.40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

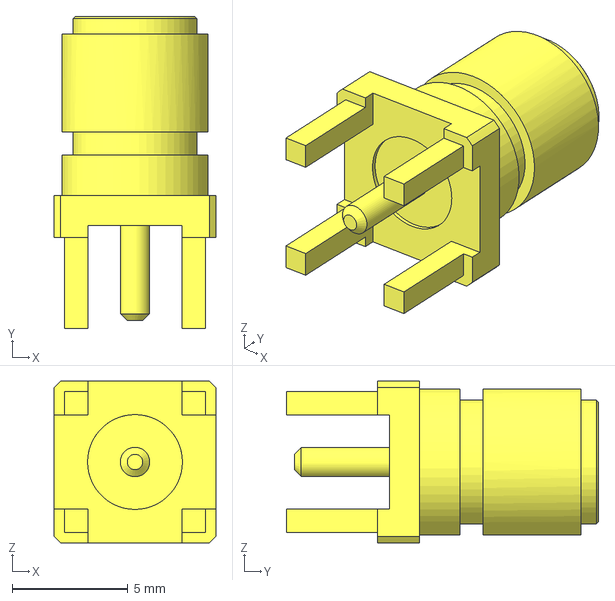
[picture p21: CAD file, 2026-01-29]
Librairies/3dmodels/SMA-J-P-H-ST-TH1.stp
7.00 x 13.5 x 7.00 mm

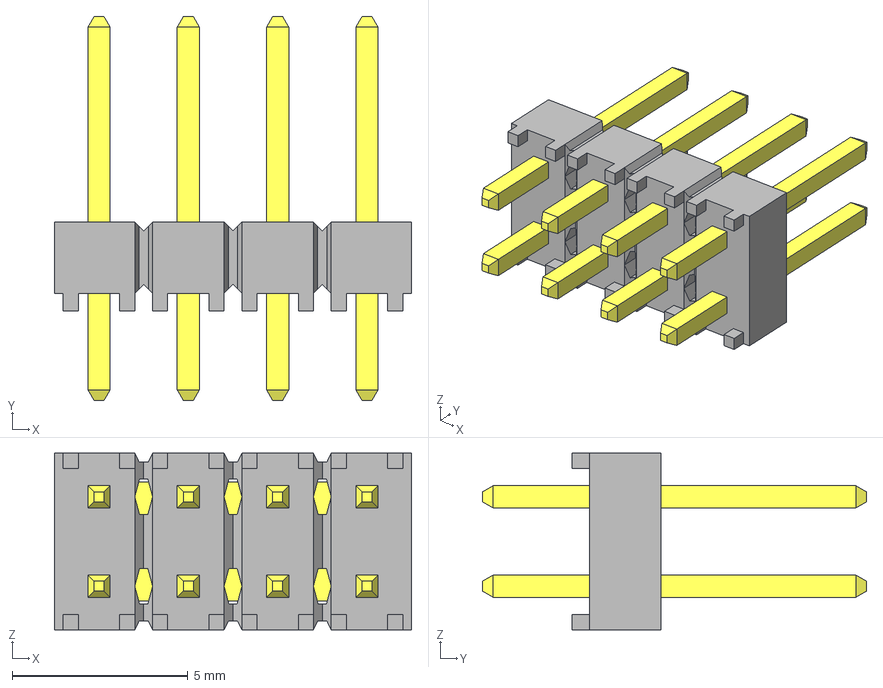
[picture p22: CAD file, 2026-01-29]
Librairies/3dmodels/HTSW-104-07-G-D.step
10.2 x 10.9 x 5.03 mm
HTSW-104-07-G-D_body
T-1S6-07-HTSW-1--07-4--G-D
T-1S6-07-HTSW-1--07-4--G-D2

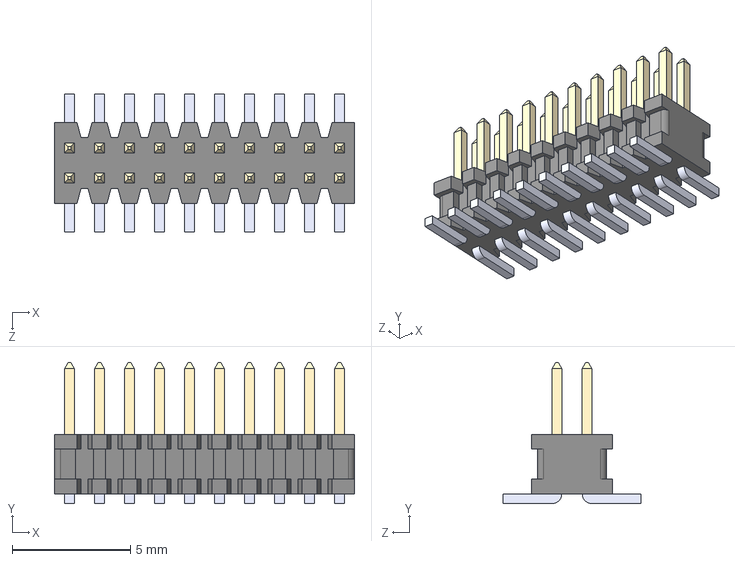
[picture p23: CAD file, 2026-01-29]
Librairies/3dmodels/FTSH-110-01-L-DV--3DModel-STEP-56544.STEP
12.7 x 5.97 x 5.84 mm

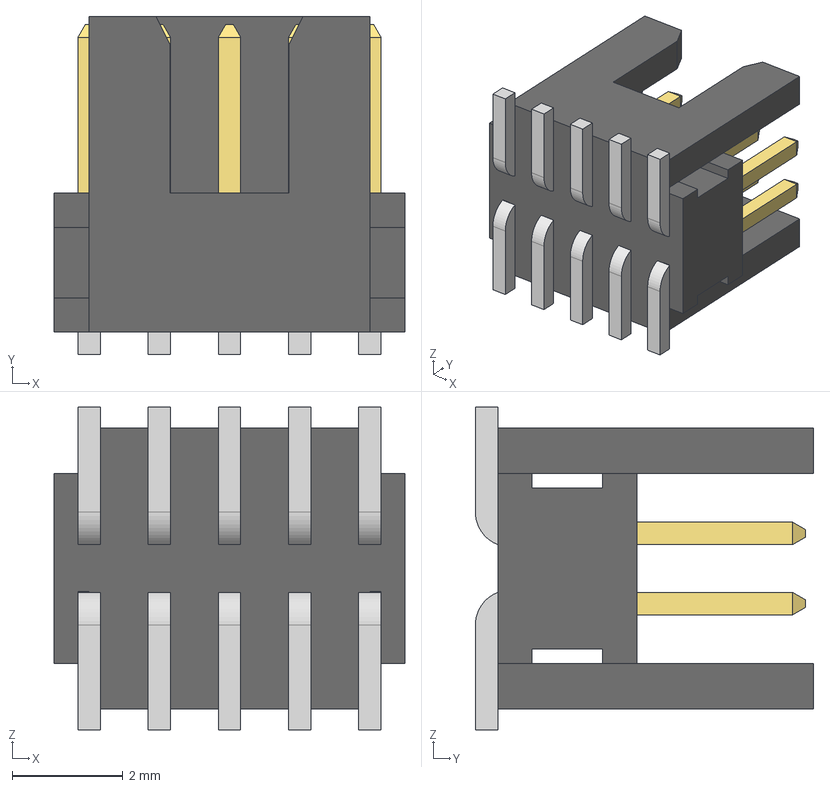
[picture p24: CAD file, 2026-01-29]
Librairies/3dmodels/FTSH-105-XX-X-DV.step
6.35 x 6.12 x 5.84 mm
FTSH-105-01-L-DV-K_body
FTSH-105-01-L-DV-K_pins1
FTSH-105-01-L-DV-K_pins2

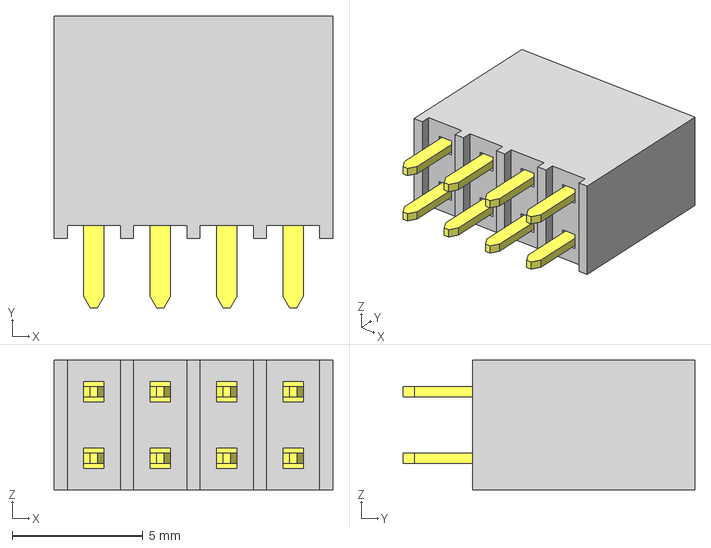
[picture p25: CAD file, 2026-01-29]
Librairies/3dmodels/SSW-104-01-G-D.step
10.7 x 11.2 x 4.95 mm
T1SSW-104-01-G-D
P2SSW-104-01-G-D

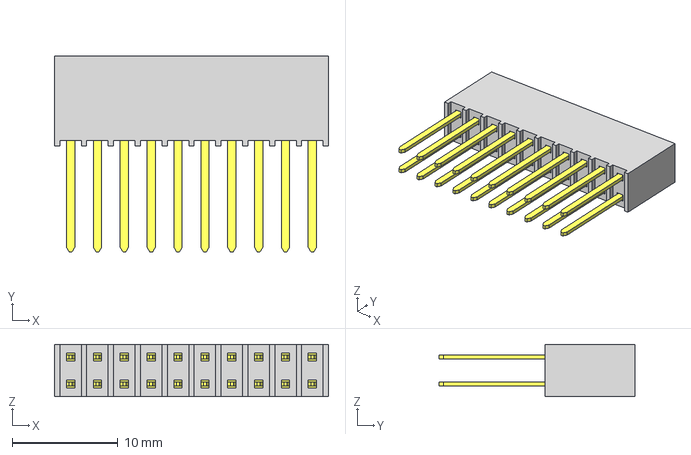
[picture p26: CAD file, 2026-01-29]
Librairies/3dmodels/SSW-110-23-H-D.step
25.9 x 18.5 x 4.95 mm
T1SSW-110-23-H-D
P2SSW-110-23-H-D

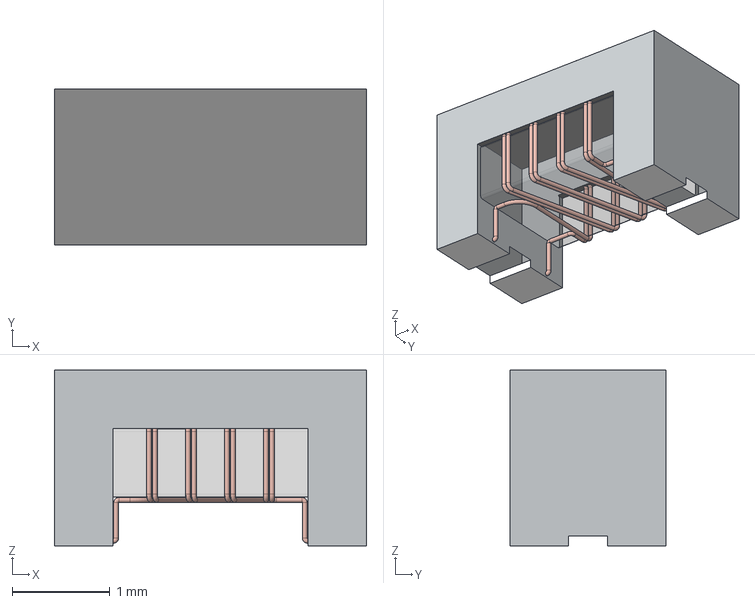
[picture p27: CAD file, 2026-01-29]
Librairies/3dmodels/L_Wurth_WE-CNSW-1206.step
3.20 x 1.60 x 1.80 mm

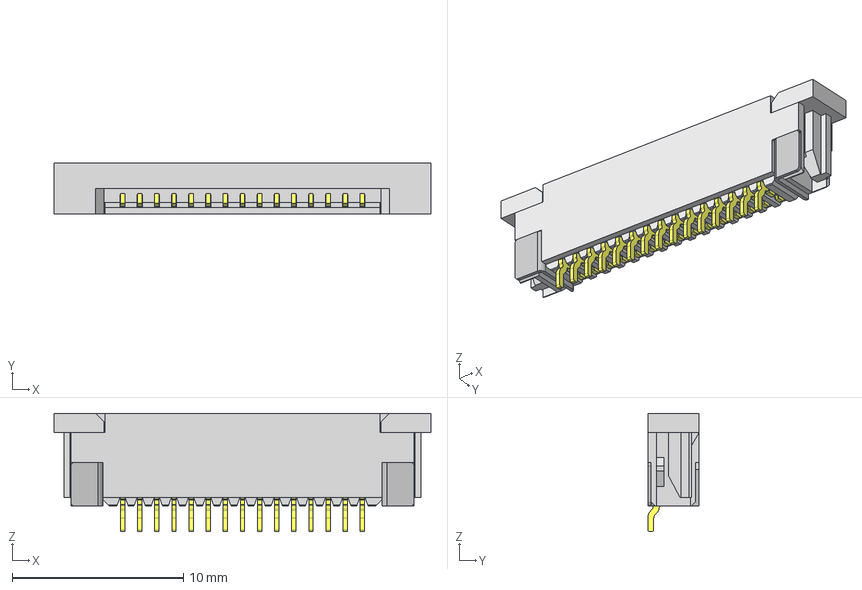
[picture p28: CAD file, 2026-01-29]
Librairies/3dmodels/ZF1-15-01-T-WT-TR.stp
22.0 x 3.01 x 6.91 mm
ZF1-15-01-WT_housing
ZF1-15-01-WT_wt
ZF1-15-01-WT_contact
ZF1-01_CS2
ZF1-01_cs

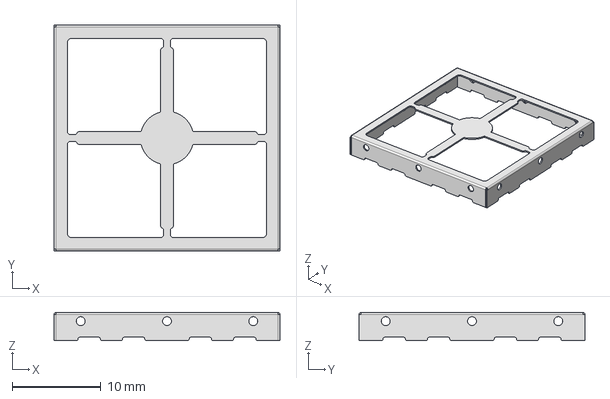
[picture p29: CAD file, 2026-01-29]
Librairies/3dmodels/H_Wurth_WE-SHC-SMT-FRAME_36103255S.step
25.4 x 25.4 x 3.20 mm

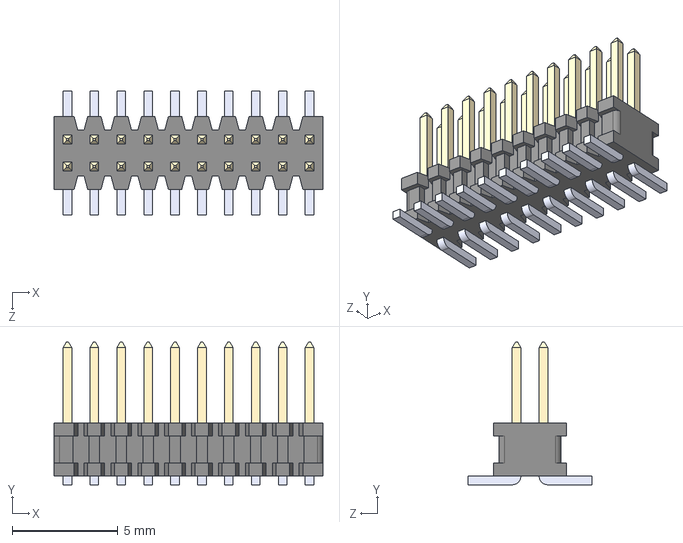
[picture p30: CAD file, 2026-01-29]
Librairies/3dmodels/FTSH-110-05-F-DV.STEP
12.7 x 6.73 x 5.84 mm

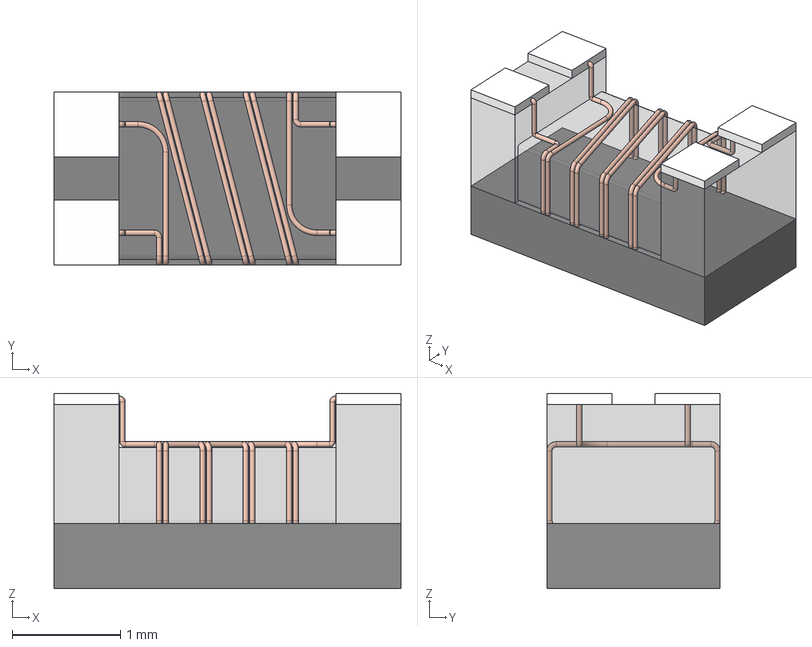
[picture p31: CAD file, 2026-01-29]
Librairies/3dmodels/WE-CNSW_1206_CNSW (rev1).stp
3.20 x 1.60 x 1.80 mm
Gehäuse
Boden
L飆fl踄he x 4

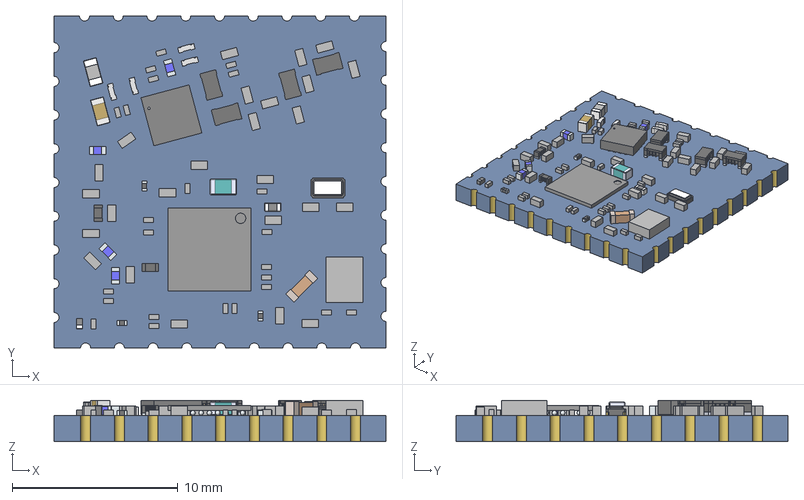
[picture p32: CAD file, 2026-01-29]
Librairies/3dmodels/ARGOS SMD.step
20.0 x 20.0 x 2.49 mm
Extruded_10 x 11
Extruded_11 x 9
Extruded_13 x 6
term1_2 x 2
term2_2 x 2
Rect1
Rect2
Rect3
Rect4
Rect5
Rect6
Rect7
Rect8
Rect9
Rect10
Rect11
term1
term2
Rect1_1
Rect2_1
Rect3_1
Rect4_1
Rect5_1
Rect6_1
Rect7_1
Rect8_1
Rect9_1
Rect10_1
Rect11_1
term1_1
term2_1
Chip Inductor 0603
Extruded_7 x 4
Extruded
Extruded_9 x 4
Extruded_15 x 3
Extruded_1
Extruded_8 x 2
Extruded_2
Extruded_3
Extruded_4
A1
A2
A4
A5
A7
A8
A9
B1_1
B2
B3
B4
B5
B6
B7
B8
B9
C1
C2
C3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

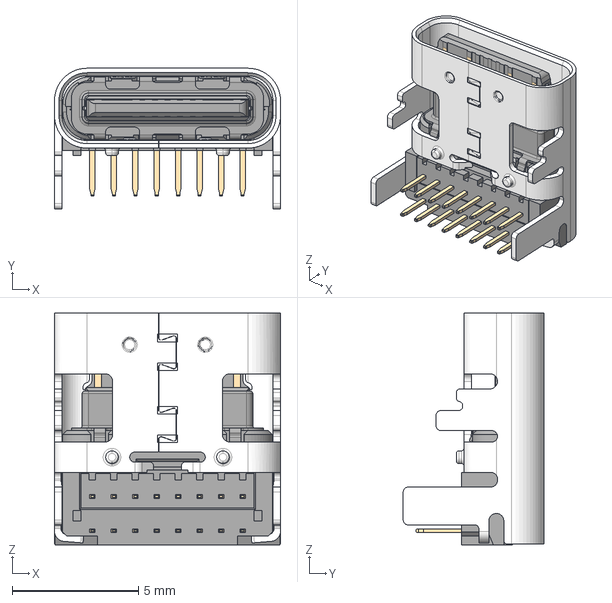
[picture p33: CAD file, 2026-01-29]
Librairies/3dmodels/usb4085-gf-a.stp
8.94 x 5.56 x 9.17 mm

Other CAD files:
Librairies/3dmodels/FJ-15-D-02.00-4.stp
Librairies/3dmodels/60312002114503 (rev1).stp
Librairies/3dmodels/LD59150PURY.stp

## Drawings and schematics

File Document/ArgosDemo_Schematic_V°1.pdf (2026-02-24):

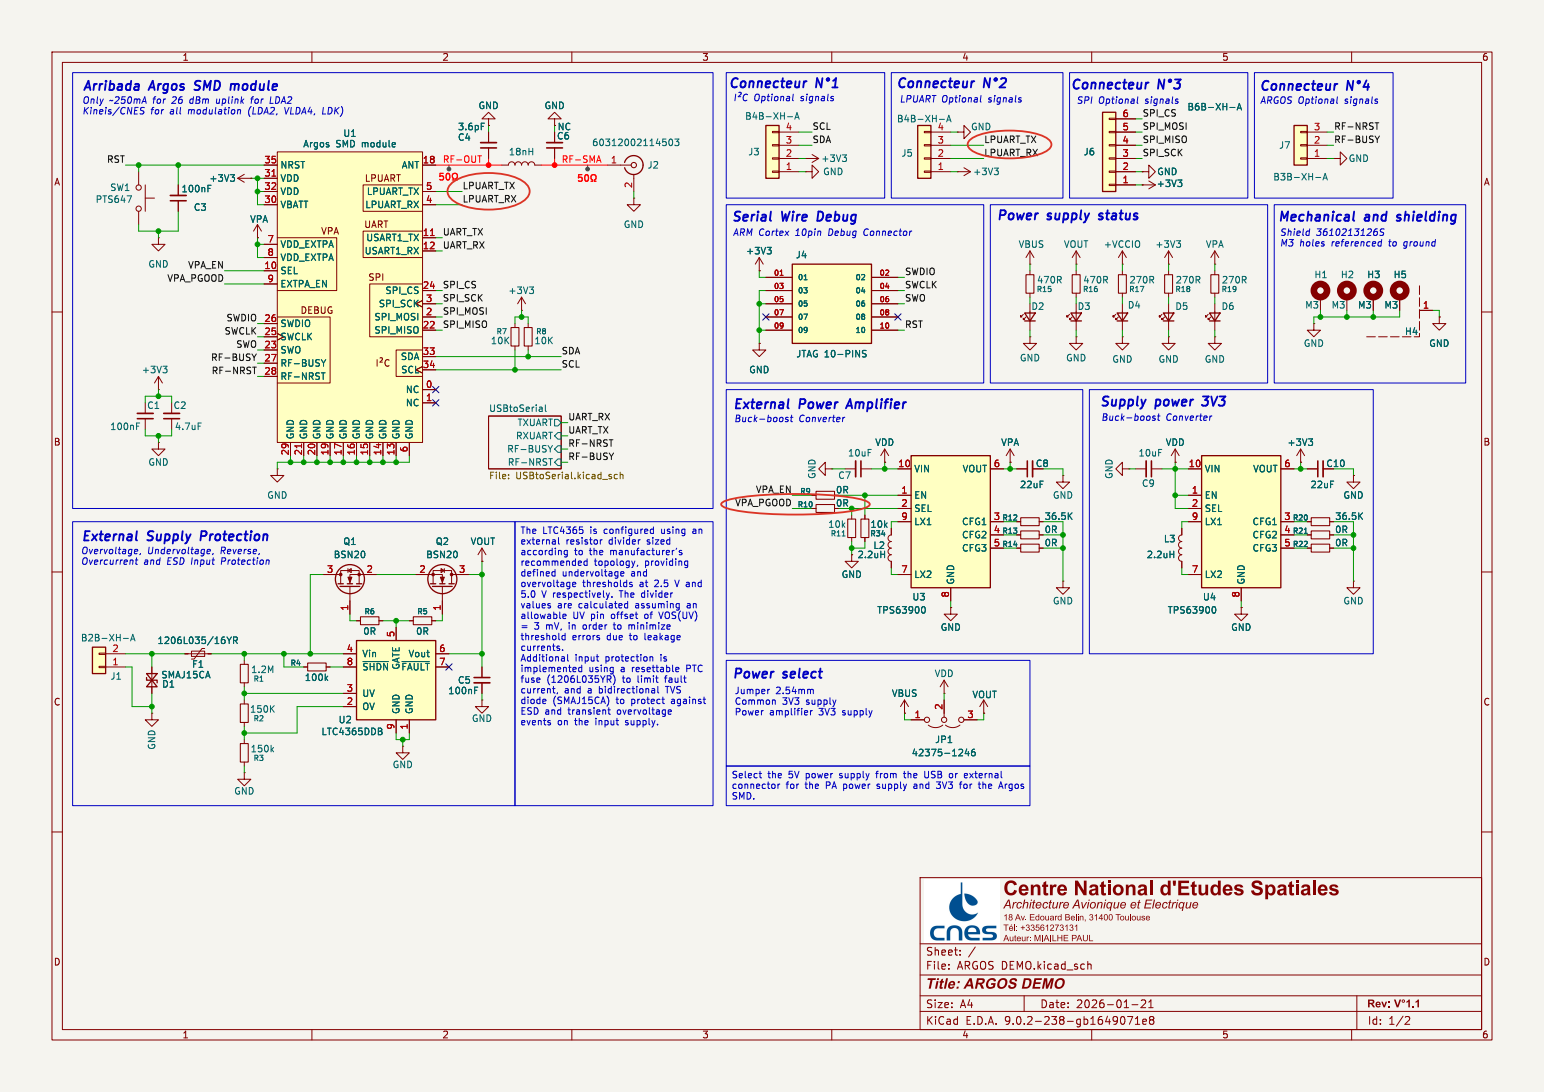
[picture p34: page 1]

Architecture Avionique et Electrique
18 Av. Edouard Belin, 31400 Toulouse
þÿTél: +33561273131 Auteur: MIAILHE PAUL

Id: 1/2 Title: ARGOS DEMO

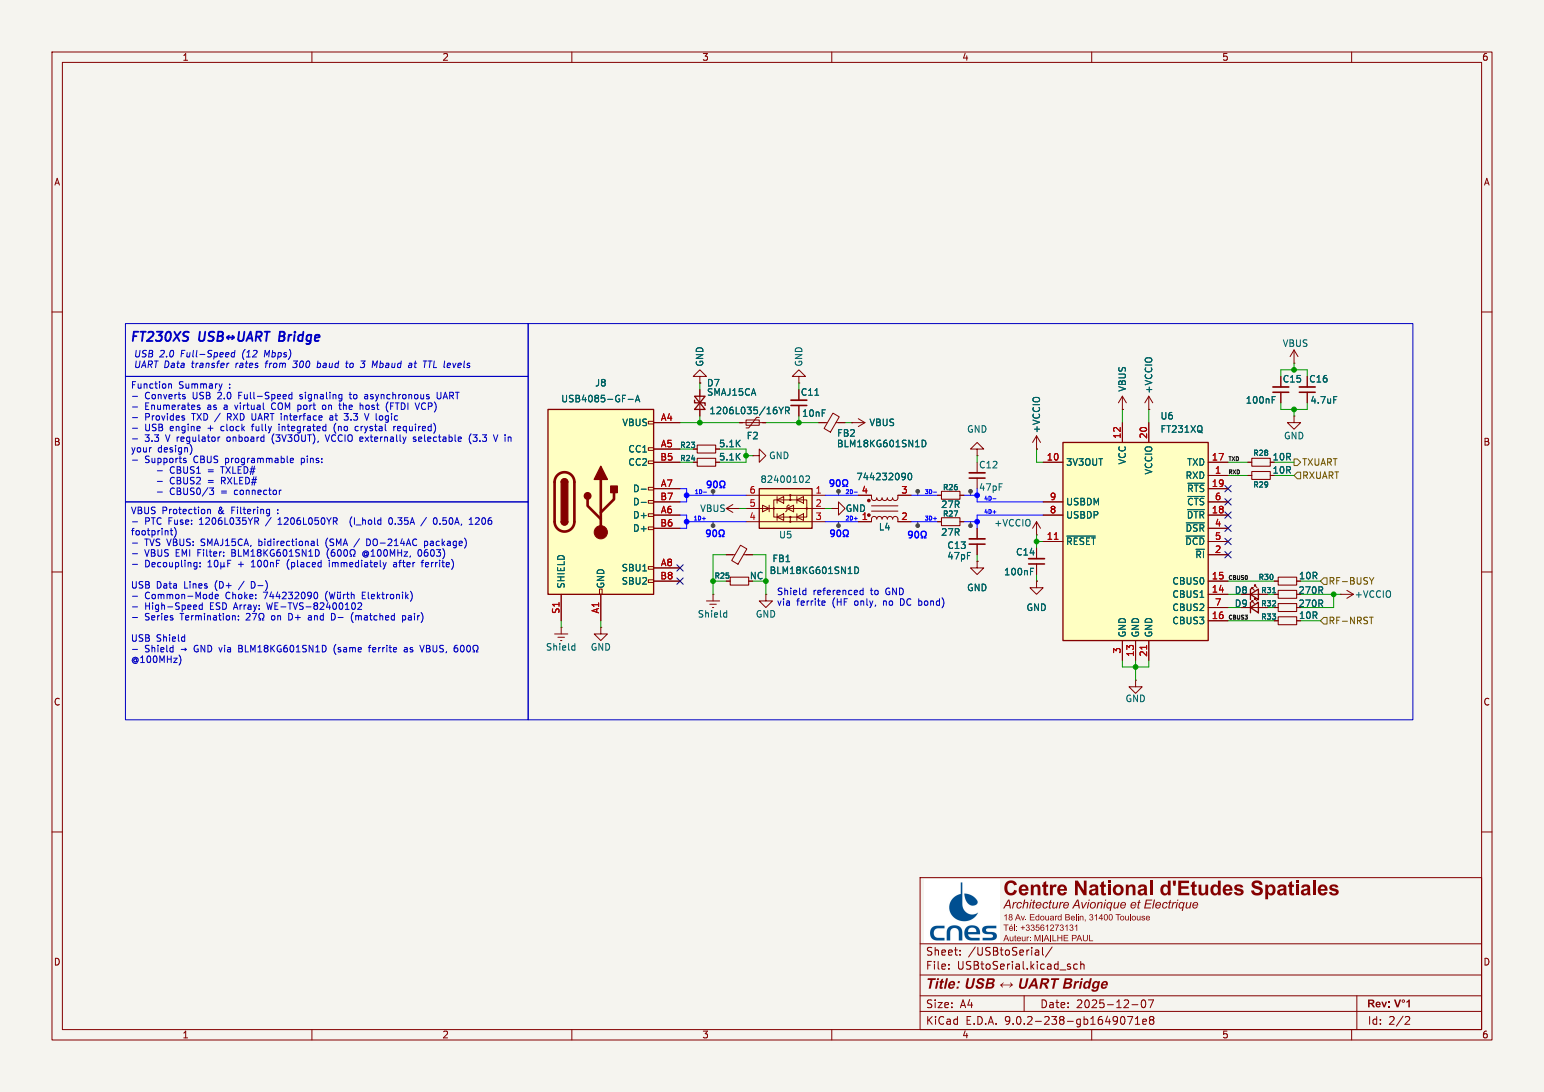
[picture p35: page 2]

3 GND 13 VCCIO 20 GND 21 TXD 17 RXD 1 ~{RTS}19 ~{CTS}6 ~{DTR}18 ~{DSR}4 ~{DCD}5 ~{RI}2 CBUS0 15 CBUS1 14 CBUS2 7 CBUS3 16 C15

3 GND 13 VCCIO 20 GND 21 TXD 17 RXD 1 ~{RTS}19 ~{CTS}6 ~{DTR}18 ~{DSR}4 ~{DCD}5 ~{RI}2 CBUS0 15 CBUS1 14 CBUS2 7 CBUS3 16 U6 FT231XQ

File: USBtoSerial.kicad_sch Sheet: /USBtoSerial/ Centre National d'Etudes Spatiales

Architecture Avionique et Electrique

þÿTél: +33561273131 Auteur: MIAILHE PAUL

Id: 2/2 Title: USB þÿ!”UART Bridge

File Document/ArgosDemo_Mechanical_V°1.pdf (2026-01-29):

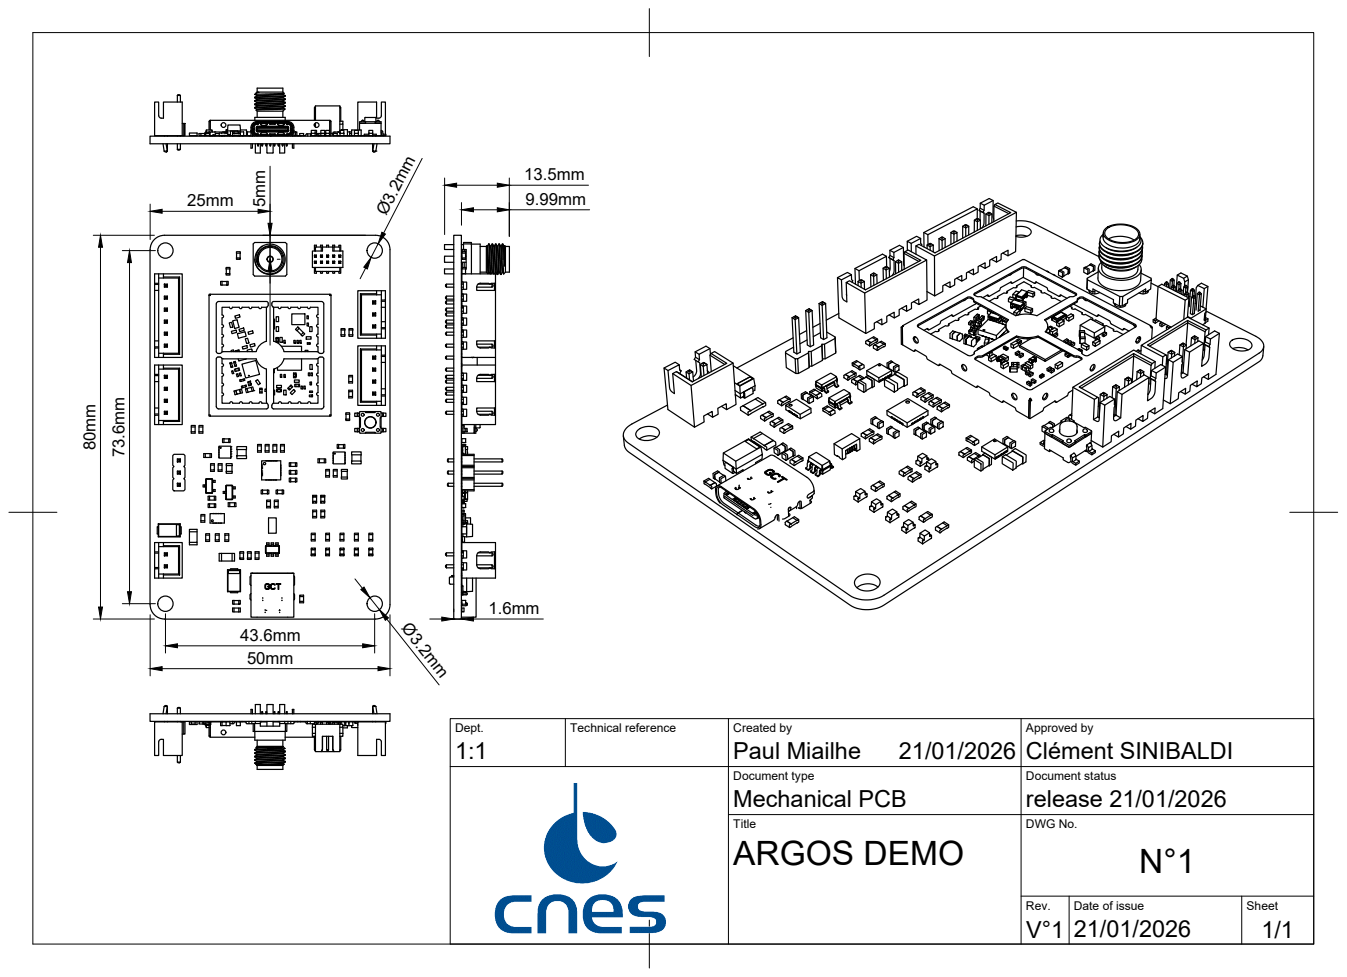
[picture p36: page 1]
Dept.; Technical reference; Created by; Approved by; Document type; Document status; Title; DWG No.; Rev.; Date of issue; Sheet; Mechanical PCB; release 21/01/2026; ARGOS DEMO; Paul Miailhe; Clément SINIBALDI 80mm

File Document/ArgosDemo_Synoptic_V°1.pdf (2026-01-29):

# ARGOS Signal

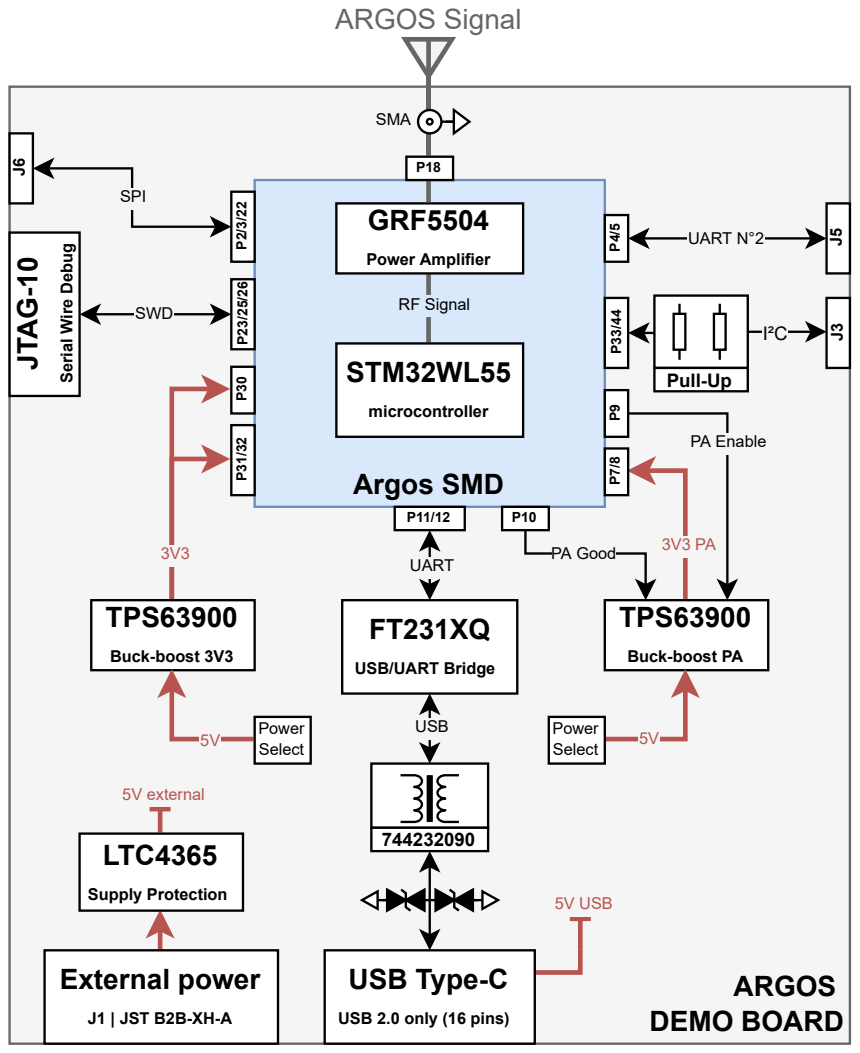
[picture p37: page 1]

TITLE : SYNOPTIC ARGOS DEMO BOARD
AUTHOR : MIAILHE PAUL 2025

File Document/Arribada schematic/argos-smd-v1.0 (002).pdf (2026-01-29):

D | D
C | C
B | B
A | A

## Arribada Initiative https://github.com/arribada contact@arribada.org arribada.org

5 | UK - Portsmouth

# HorizonLink-SMD

# argos-smd

22/11/2024 | 16:59:52

## D:\Altium\Projects\stm32wl-dev\Projects\argos-smd-hw\Project_Overview.SchDoc

## Title

Size: | Reference:

## Date: File:

## Revision:

Time: | Sheet | of
A4 | 1.0
Table of contents | Legend

General comment such as function title, configuration, ...

Sheet 2: module-BGA-RG | Text to be added to silkscreen.

## Sheet 1: Project overview (this page)

# HorizonLink-SMD

# argos-smd

## Sheet 3: stm32wl55jci7-details

Device Sheets: | Warning text.

# OPEN HARDWARE LICENSE AGREEMENT

## Sheet 5: CLS_1W_3.3V_Lineup

## Sheet 4: STM32RF_power_SMPS

## argos-smd-module

The Open Hardware License Agreement (“Agreement”) is a binding legal contract between you ("You") and the creators of this design, as represented by the Arribada Initiative, under the terms of the GNU General Public License version 3 (“GPLv3”). This license governs the use, modification, and distribution of the open-design PCB and any associated design files or materials (collectively referred to as the “Reference Material”).

By accessing, using, or modifying the Reference Material, You agree to be bound by the terms and conditions of the GPLv3. If you do not agree to these terms, do not use the Reference Material. Your use of the Reference Material constitutes acceptance of this Agreement.

The complete GNU General Public License version 3 can be found at www.gnu.org/licenses/gpl-3.0.html.

For more details about this open-design PCB project and its licensing, please visit the Arribada Initiative website or contact us directly.

The Argos SMD module is a small PCB (2x2cm) dedicated to act as a standalone or a coprocessor for any new design which required a satelite communication. The module is based on STM32WL55 processor and combined with GR5504 power amplifier allowing a comunication up to 27dBm. This module which pass the CLS certification is ready to be used.

## Notes to generate the

board layout.

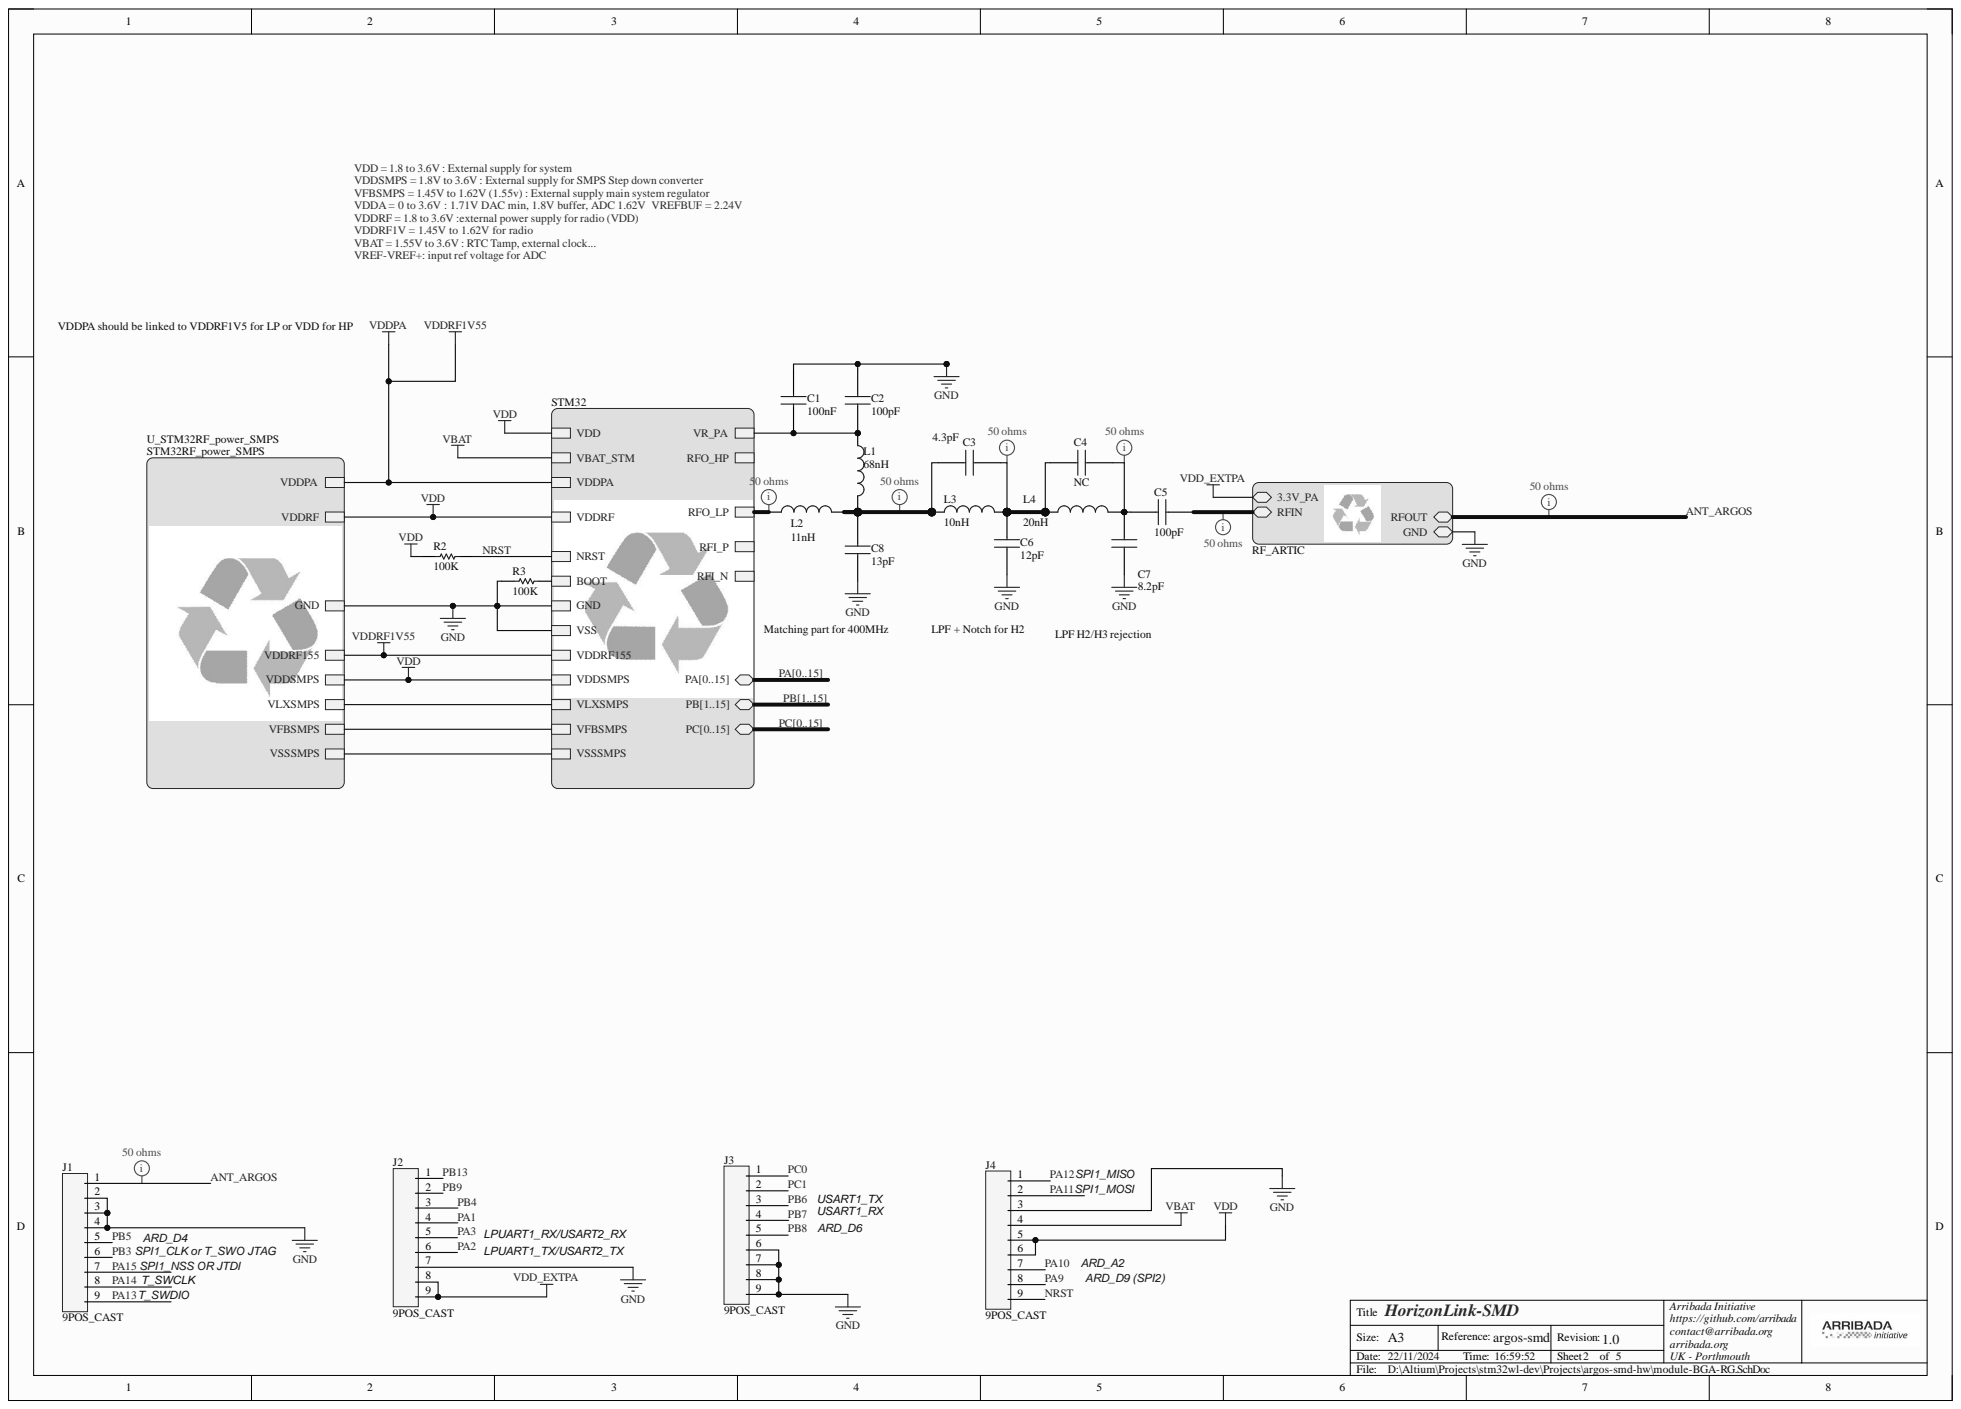
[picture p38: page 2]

VDD = 1.8 to 3.6V : External supply for system
VDDSMPS = 1.8V to 3.6V : External supply for SMPS Step down converter
VFBSMPS = 1.45V to 1.62V (1.55v) : External supply main system regulator
VDDA = 0 to 3.6V : 1.71V DAC min, 1.8V buffer, ADC 1.62V VREFBUF = 2.24V
VDDRF = 1.8 to 3.6V :external power supply for radio (VDD)
VDDRF1V = 1.45V to 1.62V for radio
VBAT = 1.55V to 3.6V : RTC Tamp, external clock...
VREF-VREF+: input ref voltage for ADC

VDDPA should be linked to VDDRF1V5 for LP or VDD for HP

Arribada Initiative
https://github.com/arribada
contact@arribada.org
arribada.org

D:\Altium\Projects\stm32wl-dev\Projects\argos-smd-hw\module-BGA-RG.SchDoc

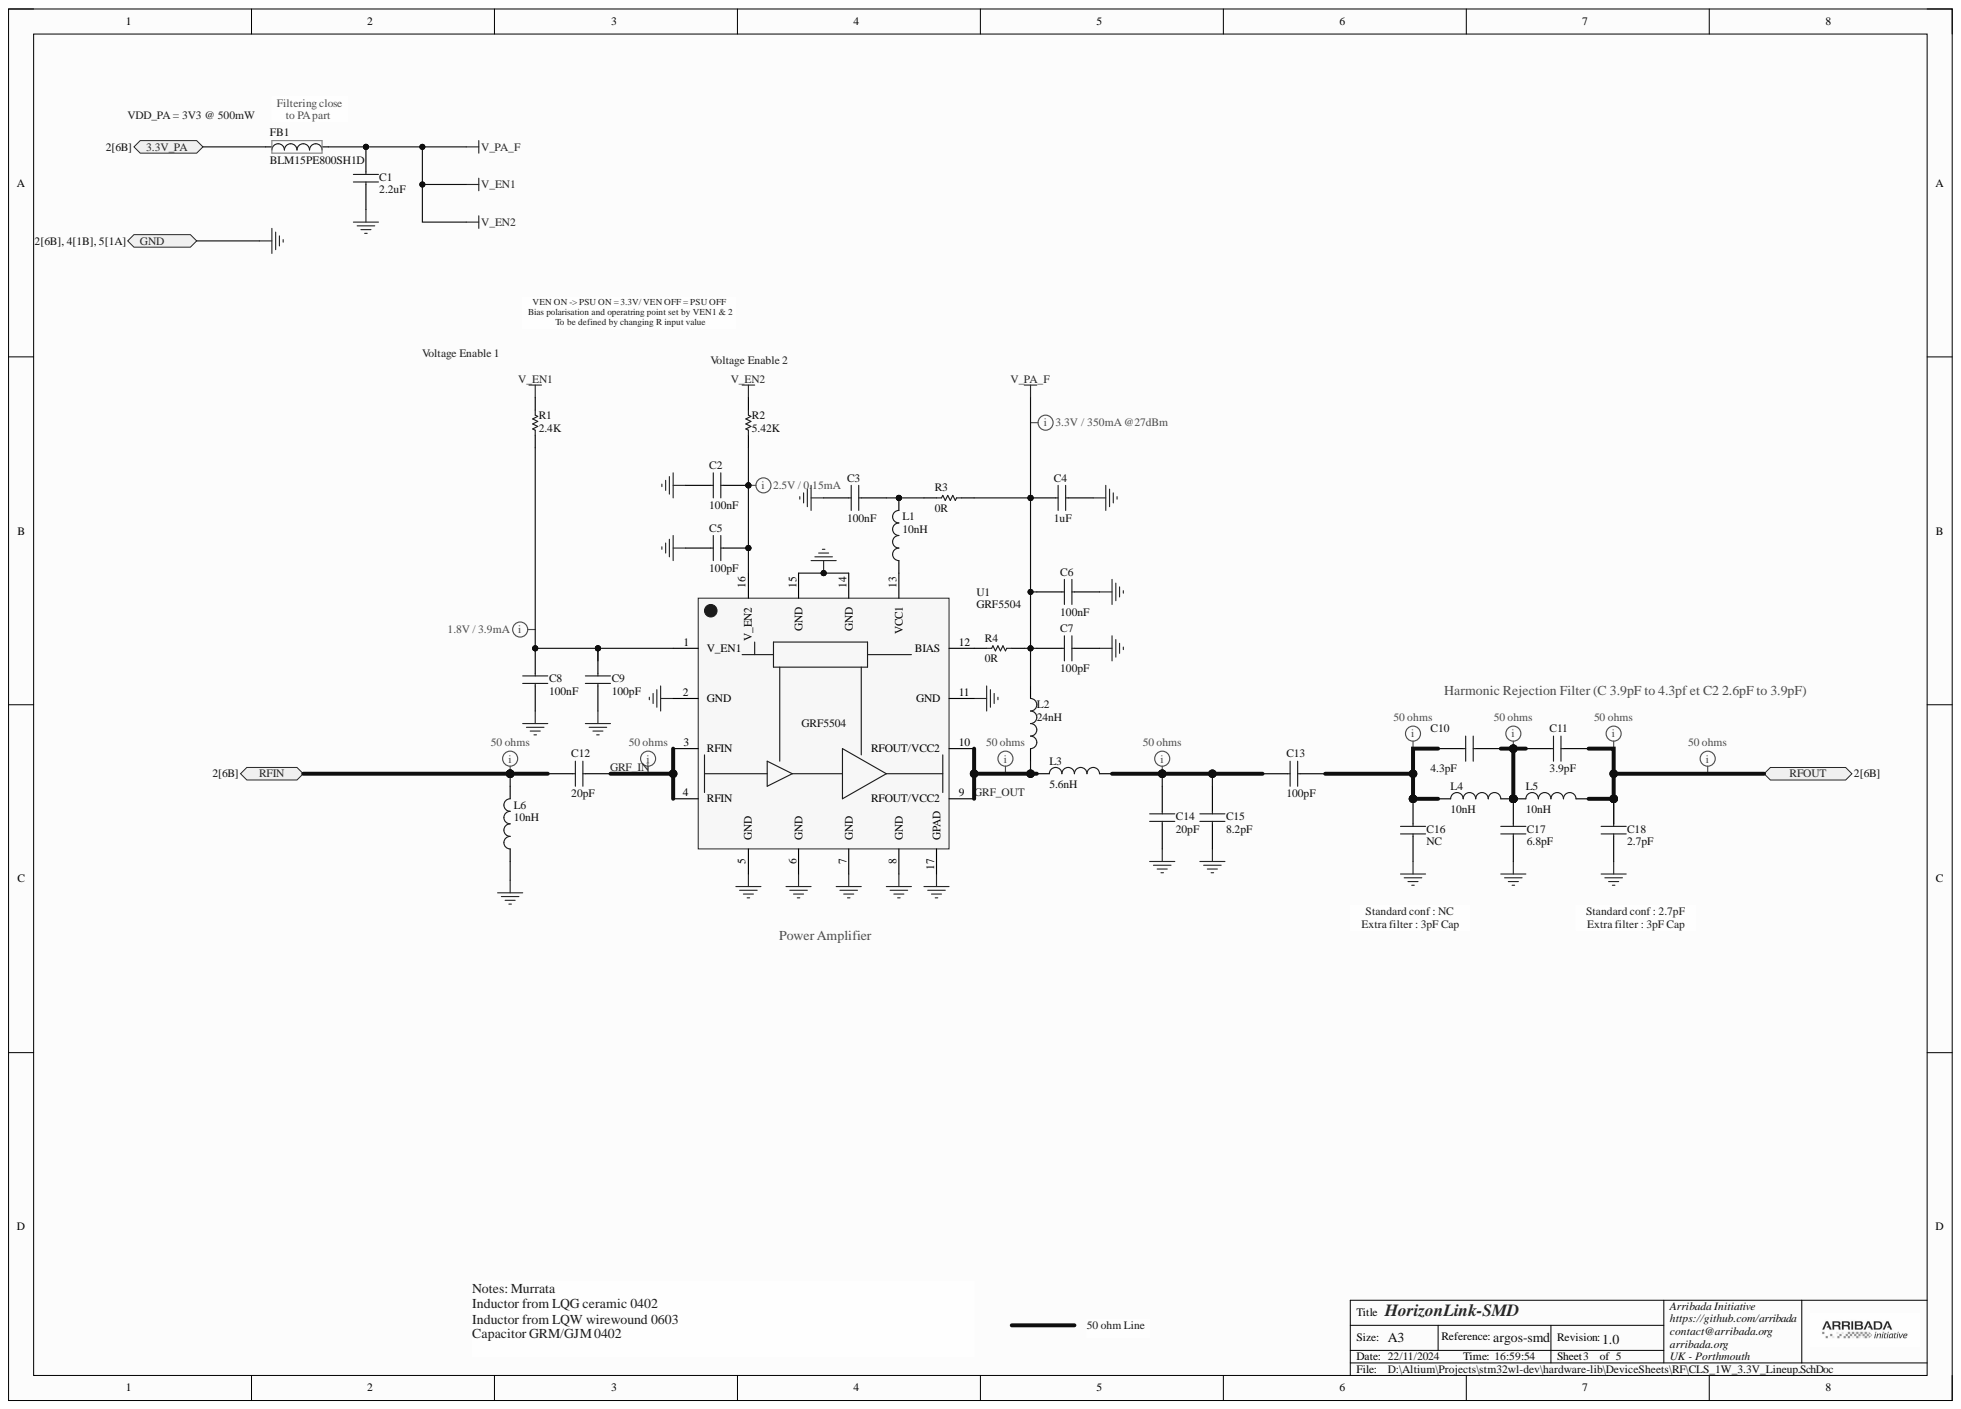
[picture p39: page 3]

VEN ON -> PSU ON = 3.3V/ VEN OFF = PSU OFF
Bias polarisation and operatring point set by VEN1 & 2

To be defined by changing R input value

Harmonic Rejection Filter (C 3.9pF to 4.3pf et C2 2.6pF to 3.9pF)

Notes: Murrata
Inductor from LQG ceramic 0402
Inductor from LQW wirewound 0603
Capacitor GRM/GJM 0402

Arribada Initiative
https://github.com/arribada
contact@arribada.org
arribada.org

D:\Altium\Projects\stm32wl-dev\hardware-lib\DeviceSheets\RF\CLS_1W_3.3V_Lineup.SchDoc

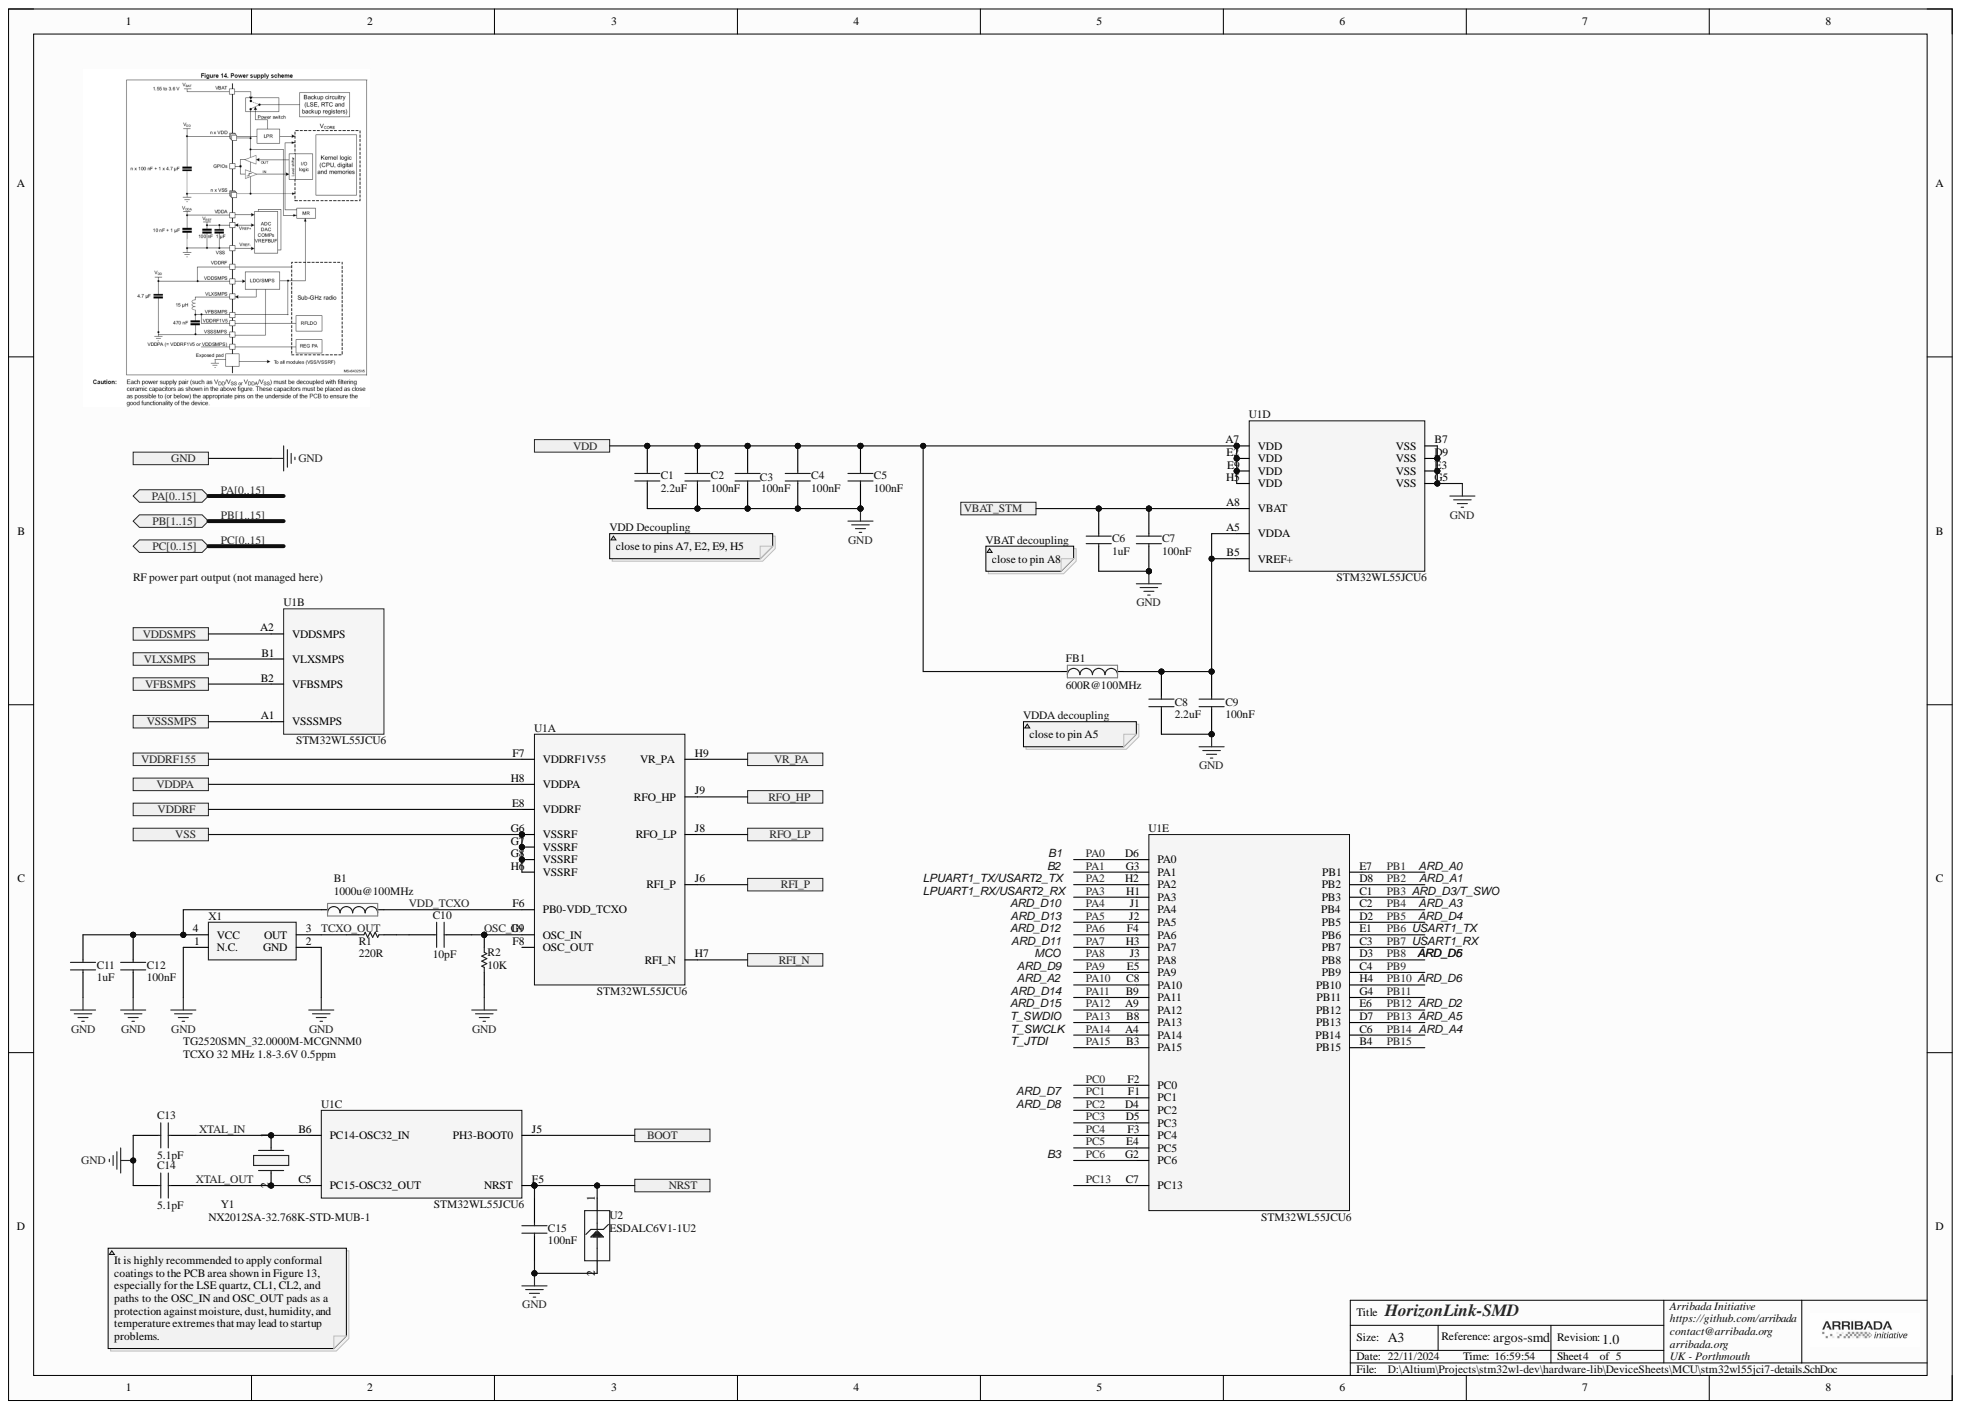
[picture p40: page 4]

RF power part output (not managed here)

VLXSMPS | VFBSMPS B2

VDDRF155 | VDDPA H8 | VR_PA

It is highly recommended to apply conformal
coatings to the PCB area shown in Figure 13,
especially for the LSE quartz, CL1, CL2, and
paths to the OSC_IN and OSC_OUT pads as a
protection against moisture, dust, humidity, and
temperature extremesthat may lead to startup
problems.

Arribada Initiative
https://github.com/arribada
contact@arribada.org
arribada.org

D:\Altium\Projects\stm32wl-dev\hardware-lib\DeviceSheets\MCU\stm32wl55jci7-details.SchDoc

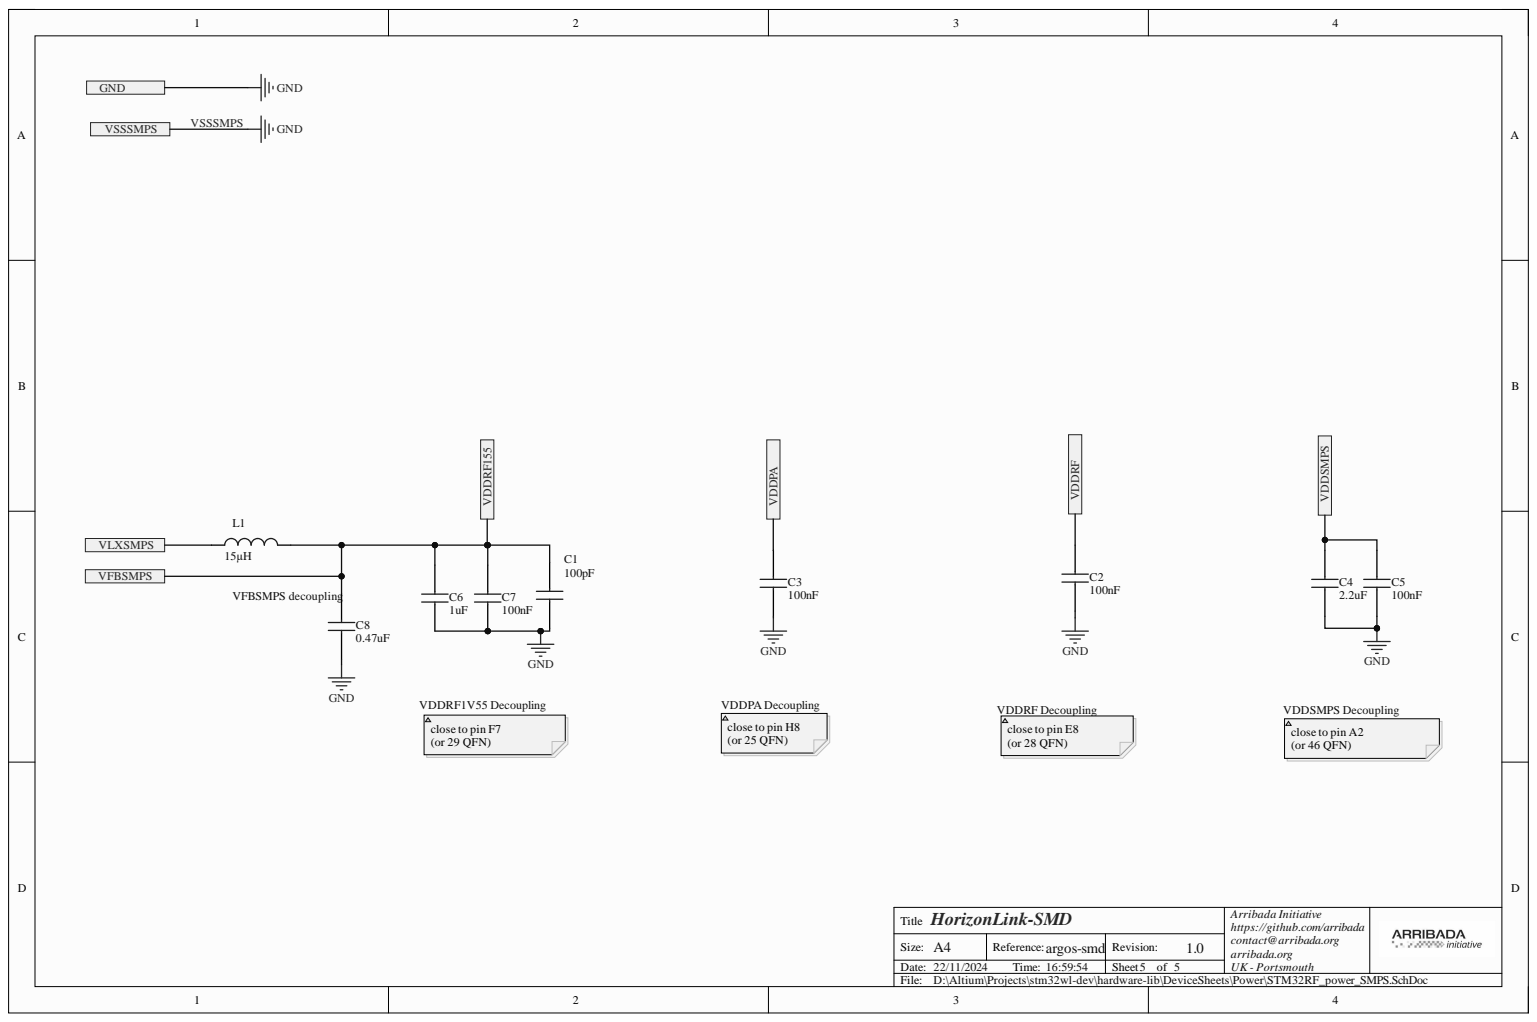
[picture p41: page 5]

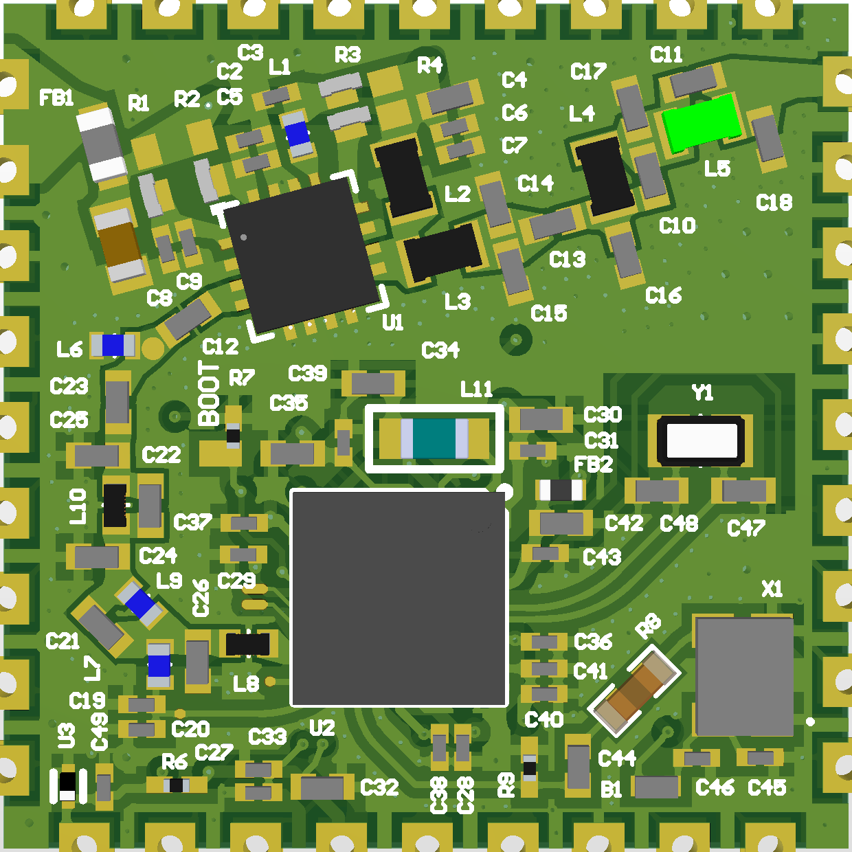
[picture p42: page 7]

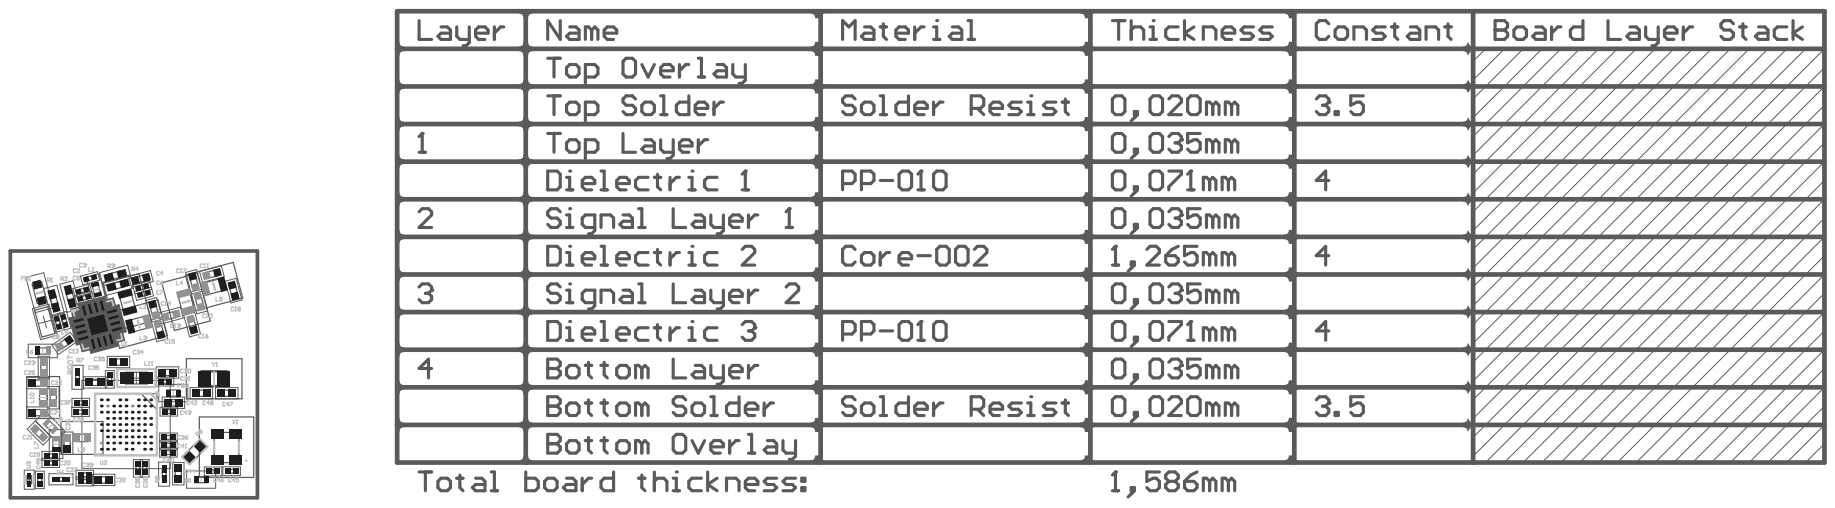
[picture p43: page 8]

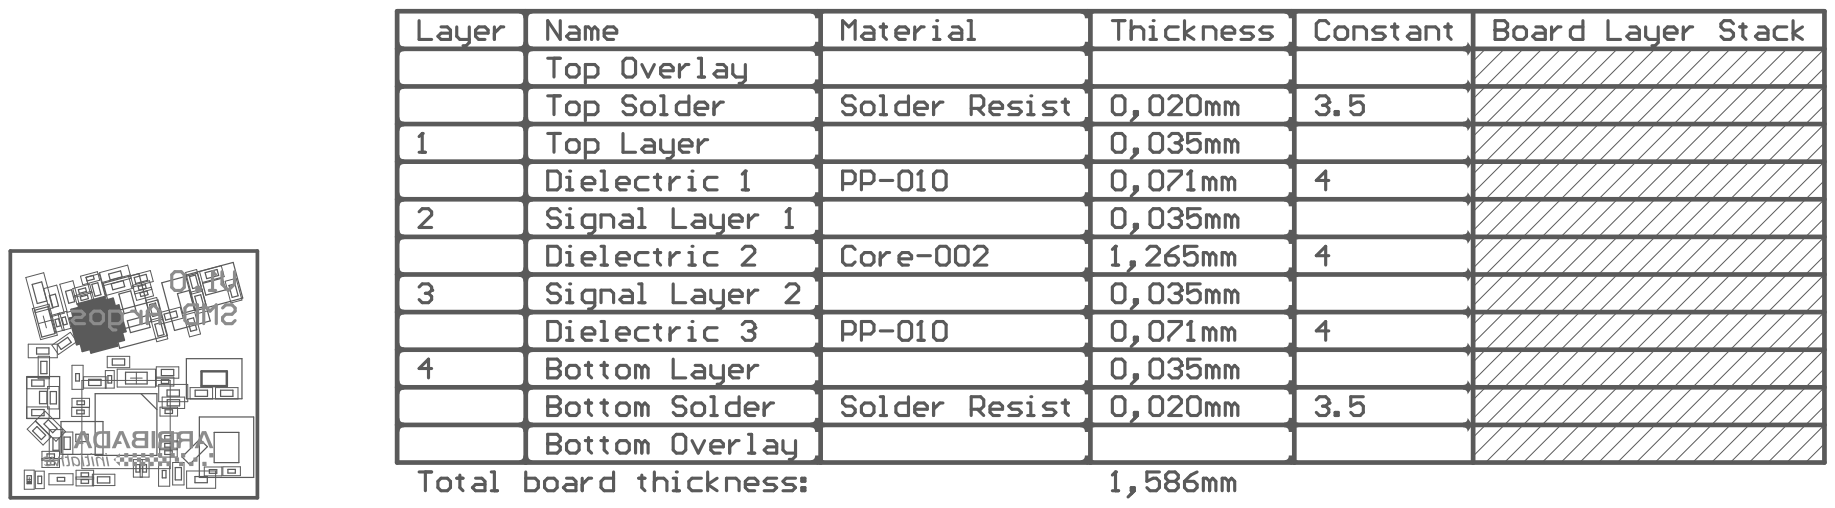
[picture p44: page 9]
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

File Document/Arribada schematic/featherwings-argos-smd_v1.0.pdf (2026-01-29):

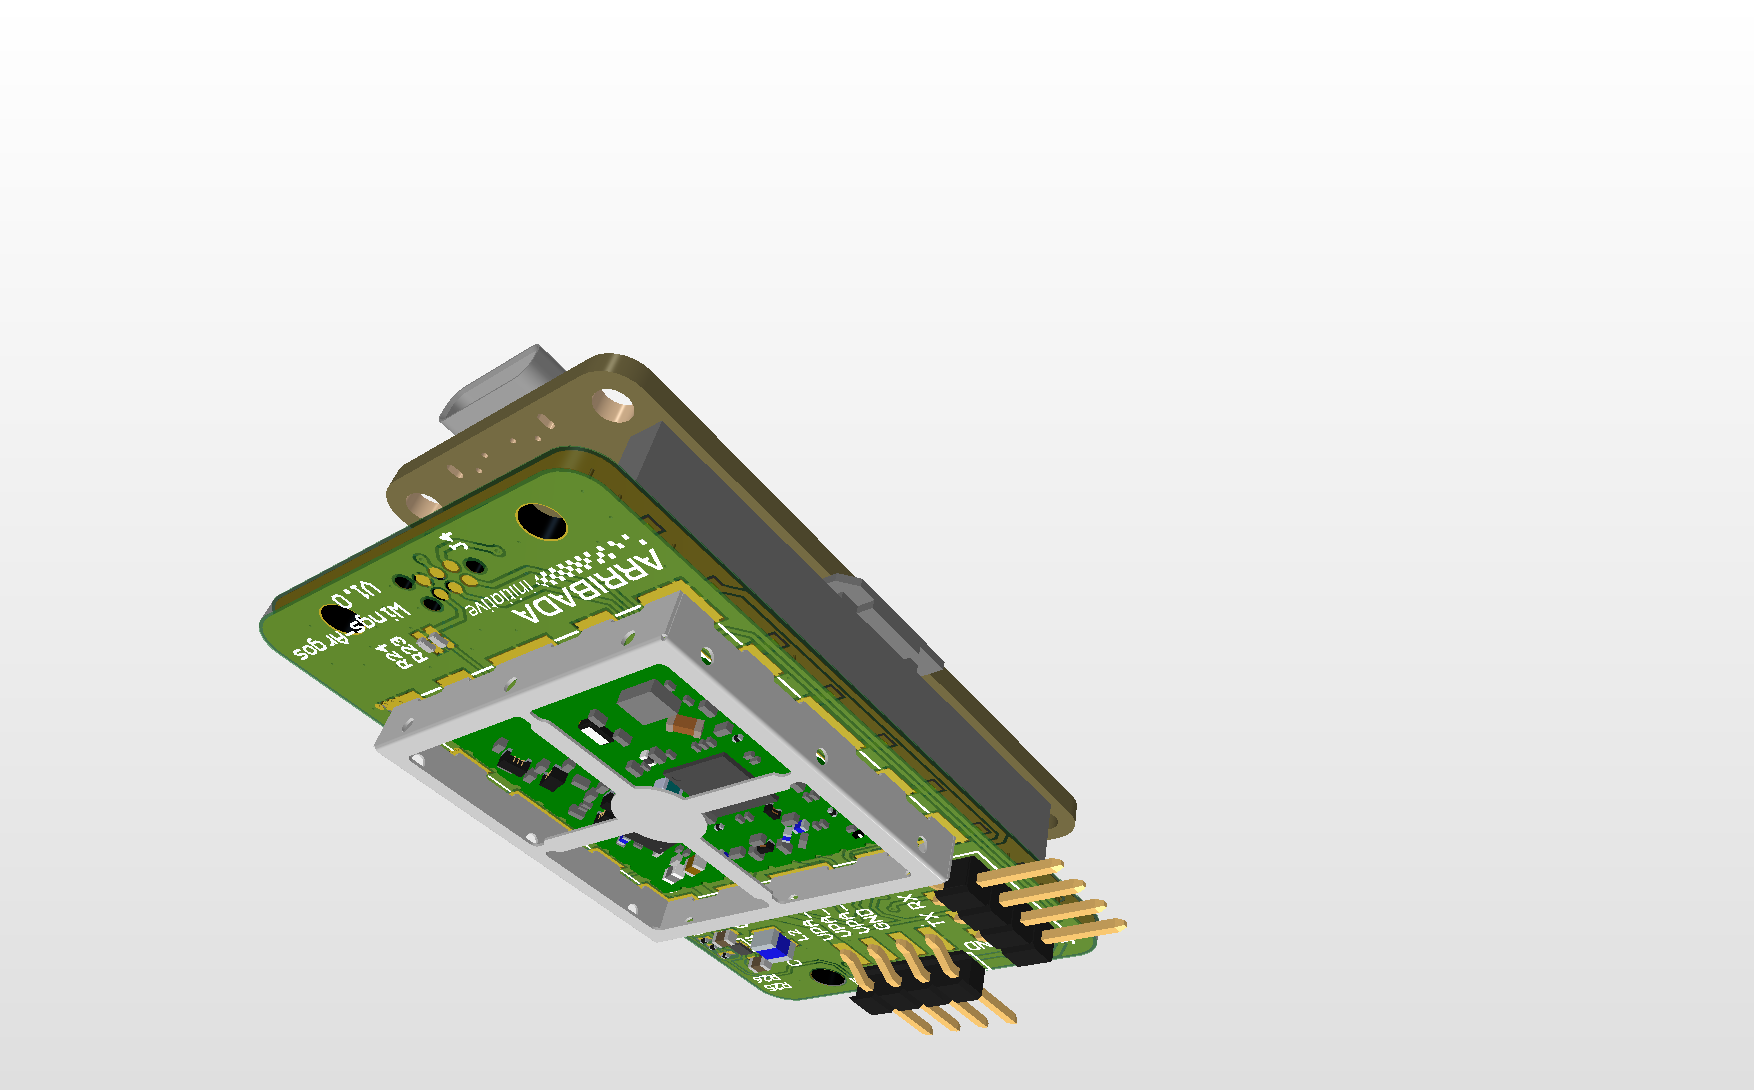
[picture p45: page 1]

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
D | D
C | C
B | B
A | A

1

Arribada Initiative
https://github.com/arribada contact@arribada.org
arribada.org
3 | UK - Portsmouth

## HorizonLink-Wings_Breakout

smd-wings | A
22/11/2024 | 17:04:34
D:\Altium\Projects\stm32wl-dev\Projects\featherwings-argos-smd\Project_Overview.SchDoc

Title

Size: | Reference:

Date:
File:

Revision:

Time: | Sheet | of
A4 | 1.0
Table of contents | Legend

General comment such as function title, configuration, ...

Sheet 2: SMD_Breakout | Text to be added to silkscreen.

Sheet 1: Project overview (this page)

# HorizonLink-Wings_Breakout

# smd-wings

Sheet 3: TPS63901_BuckBoost_lowIq_3V3_400mA

Device Sheets: | Warning text.

# OPEN HARDWARE LICENSE AGREEMENT

smd-wings

Feather wing for the ARGOS-SMD module. This breakout board can be used with a Feather board (from Adafruit) to connect the ARGOS-SMD module. It exposes the ARGOS-SMD module pins to the Feather board and includes a specific LDO to power the RF amplifier.

The Open Hardware License Agreement (“Agreement”) is a binding legal contract between you ("You") and the creators of this design, as represented by the Arribada Initiative, under the terms of the GNU General Public License version 3 (“GPLv3”). This license governs the use, modification, and distribution of the open-design PCB and any associated design files or materials (collectively referred to as the “Reference Material”).

By accessing, using, or modifying the Reference Material, You agree to be bound by the terms and conditions of the GPLv3. If you do not agree to these terms, do not use the Reference Material. Your use of the Reference Material constitutes acceptance of this Agreement.

The complete GNU General Public License version 3 can be found at www.gnu.org/licenses/gpl-3.0.html.

For more details about this open-design PCB project and its licensing, please visit the Arribada Initiative website or contact us directly.

Notes to generate the
board layout.



D:\Altium\Projects\stm32wl-dev\hardware-lib\DeviceSheets\Power\TPS63901_BuckBoost_lowIq_3V3_400mA.SchDoc












Comment | Description | Designator | Footprint | LibRef | Quantity
GRM155R71C104KA88 D | Multilayer Ceramic CapacitorsMLCC-SMD/SMT0.1 uF16 VDC10%0402X7R | C1 | 0402 | GRM155R71C104KA88 D | 1

NC | Generic capacitor | C2 | CAPC1005X55N | GEN_CAP_0402 | 1
CC0402BRNPO9BN3R 6 | Multilayer Ceramic CapacitorsMLCC-SMD/SMT50V3.6pF C0G0402Tol 0.1pF | C3 | CAPC1005X55N | CC0402BRNPO9BN3R 6 | 1

GRM188R61A106MAA LJ | Multilayer Ceramic CapacitorsMLCC-SMD/SMT10uF10 VDC20%0603X5R | C4 | CAPC1608X90N | GRM188R61A106MAA LJ | 1

GRM188R61A226ME15 D | Multilayer Ceramic CapacitorsMLCC-SMD/SMT22uF10 VDC20%0603X5R | C5 | GRM18x | GRM188R61A226ME15 D | 1

MBR120LSFT3G | SchottkyDiodes& Rectifiers1A20V | D1, D2 | SODFL3616X98N | MBR120LSFT3G | 2

20279-001E-01 | CONIPEXMHFSMT RECEPTACLERFDC-6GHZVSWR: 1.3 max. at 0.1-3GHz; VSWR: 1.5 max. at 3-6GHz | J1 | MHFSMTREC | 20279-001E-01 | 1

SSM-112-F-SV-P-TR | Headers&Wire HousingsSurface Mount, 12pos, PCB Socket Strips, .100" pitch | J2 | SAMTEC_SSM-112-F-SV-P-TR | SSM-112-F-SV-P-TR | 1

SSM-116-F-SV-P-TR | Headers&Wire HousingsSurface Mount, 16pos, PCB Socket Strips, .100" pitch | J3 | SAMTEC_SSM-116-F-SV-P-TR | SSM-116-F-SV-P-TR | 1

TC2030-NL | CONPLUGOFNAILS6 PINFOOTPRINTNO LEGS | J4 | TC2030NL | TC2030-NL | 1

M20-8890445R | Connector | J5, J6 | M208890445R | M20-8890445R | 2
PRT-14417 | QWIICJST CONNECTOR- SMD4-PIN | J7 | SPARKFUN_PRT-14417 PRT-14417 | | 1

LQW18AN18NG8ZD | Inductor Wirewound, 18nH, 75Milliohm, ± 2%, 1.4A, 0603[1608 Metric] | L1 | LQW18AN10NG80D | LQW18AN18NG8ZD | 1

DFE252012F-2R2M=P2 | Inductor Power Chip ShieldedWirewound 2.2uH20%1MHz Metal 2.3A0.082Ohm DCR1008T/R | L2 | DFE2HCAH1R0MJ0L | DFE252012F-2R2M=P2 | 1

36103255S | WE-SHCShielding Cabinet, SMTFrame, TinPlated, Tray, 25x25x3mm | MP1 | 36103255S | 36103255S | 1
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

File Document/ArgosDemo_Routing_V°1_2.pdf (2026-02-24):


Architecture Avionique et Electrique
18 Av. Edouard Belin, 31400 Toulouse
þÿTél: +33561273131 Auteur: MIAILHE PAUL

Id: 1/11 Title: ARGOS DEMO


Architecture Avionique et Electrique
18 Av. Edouard Belin, 31400 Toulouse
þÿTél: +33561273131 Auteur: MIAILHE PAUL

Id: 2/11 Title: ARGOS DEMO


Architecture Avionique et Electrique
18 Av. Edouard Belin, 31400 Toulouse
þÿTél: +33561273131 Auteur: MIAILHE PAUL

Id: 3/11 Title: ARGOS DEMO


Architecture Avionique et Electrique
18 Av. Edouard Belin, 31400 Toulouse
þÿTél: +33561273131 Auteur: MIAILHE PAUL

Id: 4/11 Title: ARGOS DEMO


Architecture Avionique et Electrique
18 Av. Edouard Belin, 31400 Toulouse
þÿTél: +33561273131 Auteur: MIAILHE PAUL

Id: 5/11 Title: ARGOS DEMO


Architecture Avionique et Electrique
18 Av. Edouard Belin, 31400 Toulouse
þÿTél: +33561273131 Auteur: MIAILHE PAUL

Id: 6/11 Title: ARGOS DEMO


Architecture Avionique et Electrique

þÿTél: +33561273131 Auteur: MIAILHE PAUL

Id: 7/11 Title: ARGOS DEMO


Architecture Avionique et Electrique
18 Av. Edouard Belin, 31400 Toulouse
þÿTél: +33561273131 Auteur: MIAILHE PAUL

Id: 8/11 Title: ARGOS DEMO

Architecture Avionique et Electrique
18 Av. Edouard Belin, 31400 Toulouse
þÿTél: +33561273131 Auteur: MIAILHE PAUL

Id: 9/11 Title: ARGOS DEMO


Architecture Avionique et Electrique
18 Av. Edouard Belin, 31400 Toulouse
þÿTél: +33561273131 Auteur: MIAILHE PAUL

Id: 10/11 Title: ARGOS DEMO

Architecture Avionique et Electrique
18 Av. Edouard Belin, 31400 Toulouse
þÿTél: +33561273131 Auteur: MIAILHE PAUL

Id: 11/11 Title: ARGOS DEMO

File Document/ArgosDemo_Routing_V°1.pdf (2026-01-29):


Architecture Avionique et Electrique
18 Av. Edouard Belin, 31400 Toulouse
þÿTél: +33561273131 Auteur: MIAILHE PAUL

Id: 1/11 Title: ARGOS DEMO


Architecture Avionique et Electrique
18 Av. Edouard Belin, 31400 Toulouse
þÿTél: +33561273131 Auteur: MIAILHE PAUL

Id: 2/11 Title: ARGOS DEMO


Architecture Avionique et Electrique
18 Av. Edouard Belin, 31400 Toulouse
þÿTél: +33561273131 Auteur: MIAILHE PAUL

Id: 3/11 Title: ARGOS DEMO


Architecture Avionique et Electrique
18 Av. Edouard Belin, 31400 Toulouse
þÿTél: +33561273131 Auteur: MIAILHE PAUL

Id: 4/11 Title: ARGOS DEMO


Architecture Avionique et Electrique
18 Av. Edouard Belin, 31400 Toulouse
þÿTél: +33561273131 Auteur: MIAILHE PAUL

Id: 5/11 Title: ARGOS DEMO


Architecture Avionique et Electrique
18 Av. Edouard Belin, 31400 Toulouse
þÿTél: +33561273131 Auteur: MIAILHE PAUL

Id: 6/11 Title: ARGOS DEMO


Architecture Avionique et Electrique

þÿTél: +33561273131 Auteur: MIAILHE PAUL

Id: 7/11 Title: ARGOS DEMO


Architecture Avionique et Electrique
18 Av. Edouard Belin, 31400 Toulouse
þÿTél: +33561273131 Auteur: MIAILHE PAUL

Id: 8/11 Title: ARGOS DEMO

Architecture Avionique et Electrique
18 Av. Edouard Belin, 31400 Toulouse
þÿTél: +33561273131 Auteur: MIAILHE PAUL

Id: 9/11 Title: ARGOS DEMO


Architecture Avionique et Electrique
18 Av. Edouard Belin, 31400 Toulouse
þÿTél: +33561273131 Auteur: MIAILHE PAUL

Id: 10/11 Title: ARGOS DEMO

Architecture Avionique et Electrique
18 Av. Edouard Belin, 31400 Toulouse
þÿTél: +33561273131 Auteur: MIAILHE PAUL

Id: 11/11 Title: ARGOS DEMO

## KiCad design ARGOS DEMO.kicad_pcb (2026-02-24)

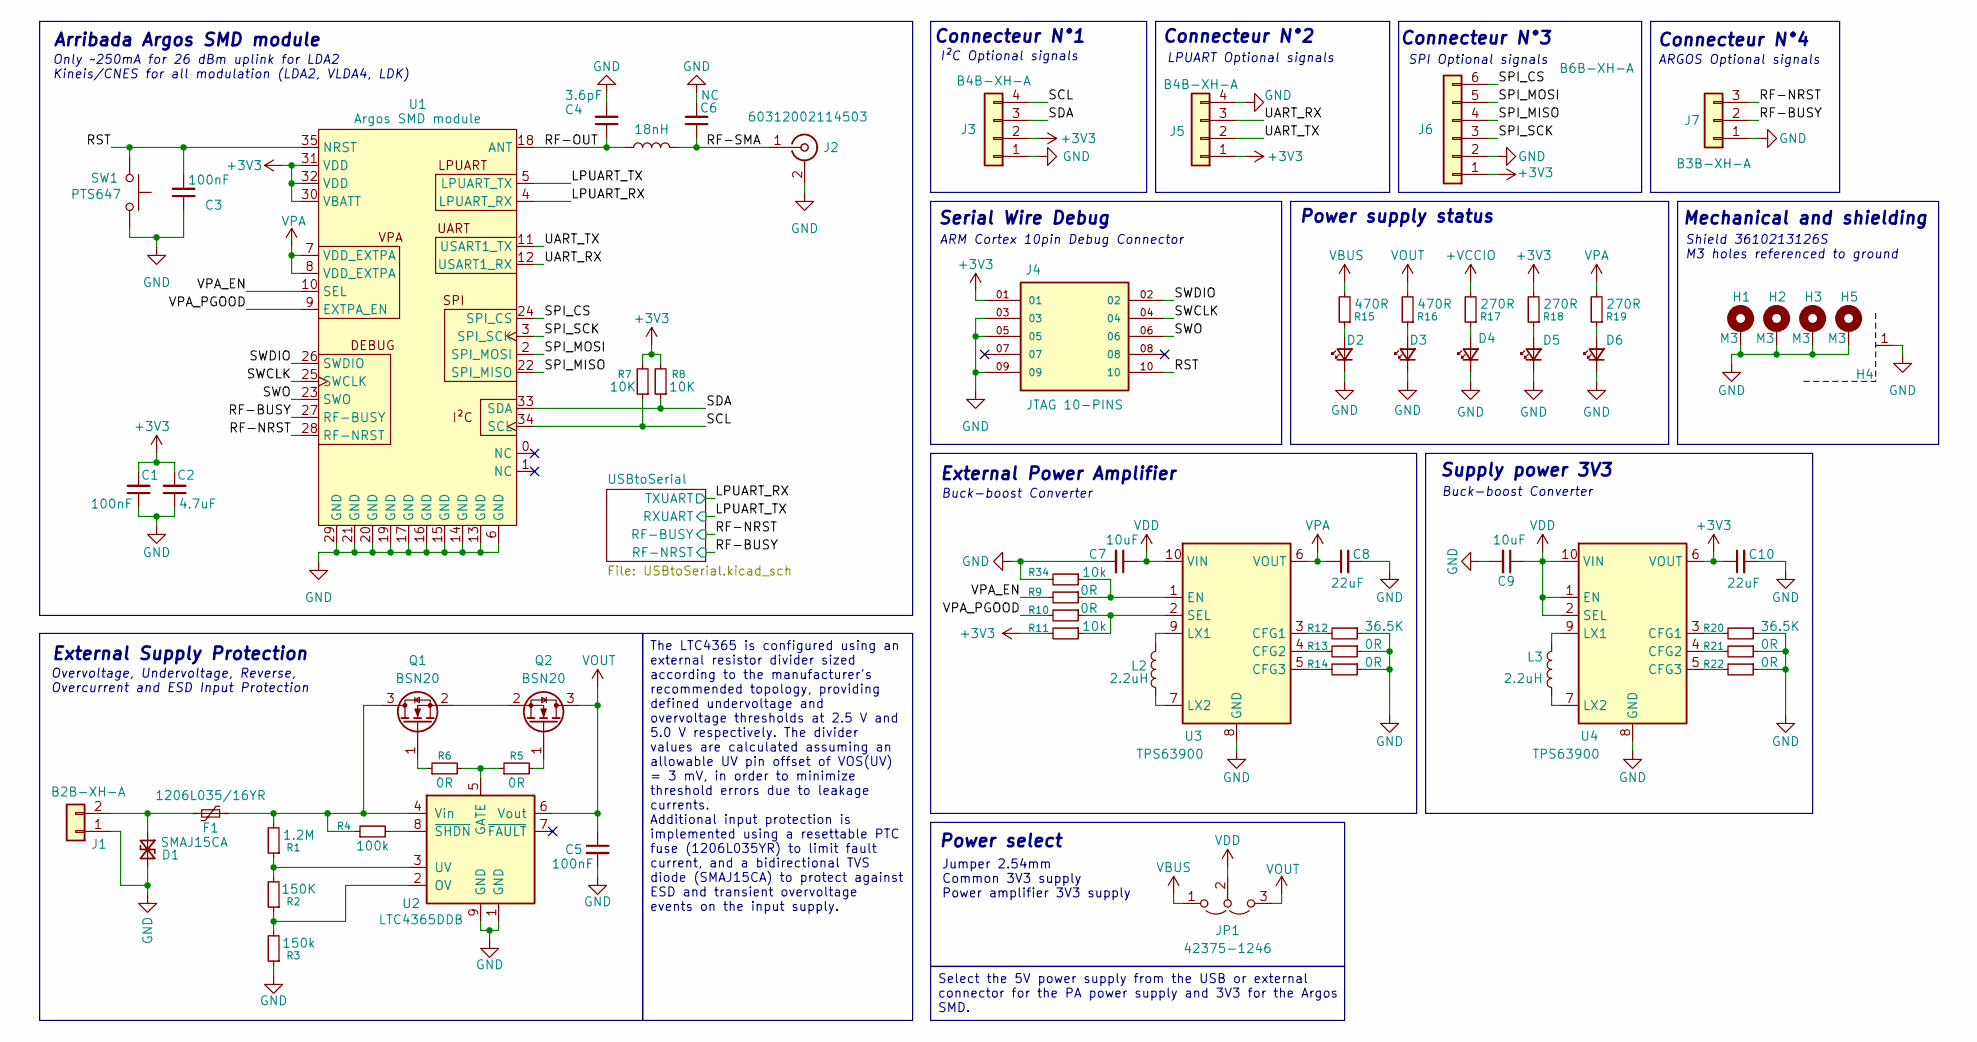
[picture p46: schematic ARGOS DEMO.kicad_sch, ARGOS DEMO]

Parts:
C1, C3, C5: 100nF; C_0603_1608Metric
C2: 4.7uF; C_0603_1608Metric
C4: 3.6pF; C_0603_1608Metric
C6: NC; C_0603_1608Metric
C7, C9: 10uF; C_0603_1608Metric
C8, C10: 22uF; C_0805_2012Metric
D1: SMAJ15CA; D_SMA
D2, D3, D4, D5, D6: LED_Small; LED_0603_1608Metric
F1: 1206L035/16YR; Fuse_1206_3216Metric
H1, H2, H3, H5: M3; MountingHole_3.2mm_M3_DIN965_Pad
H4: 3610213126S; H_Wurth_WE-SHC-SMT-FRAME_36103255S; Part Number 3610213126S
J1: B2B-XH-A; JST_XH_B2B-XH-A_1x02_P2.50mm_Vertical
J2: 60312002114503; SMA_Wurth_60312002114503_Vertical
J3, J5: B4B-XH-A; JST_XH_B4B-XH-A_1x04_P2.50mm_Vertical
J4: JTAG 10-PINS; SAMTEC_FTSH-105-XX-X-DV
J6: B6B-XH-A; JST_XH_B6B-XH-A_1x06_P2.50mm_Vertical
J7: B3B-XH-A; JST_XH_B3B-XH-A_1x03_P2.50mm_Vertical
JP1: 42375-1246; PinHeader_1x03_P2.54mm_Vertical
L1: 18nH; L_0603_1608Metric
L2, L3: 2.2uH; L_1008_2520Metric
Q1, Q2: BSN20; SOT-23
R1: 1.2M; R_0603_1608Metric
R2: 150K; R_0603_1608Metric
R3: 150k; R_0603_1608Metric
R4: 100k; R_0603_1608Metric
R5, R6, R9, R10, R13, R14, R21, R22: 0R; R_0603_1608Metric
R7, R8: 10K; R_0603_1608Metric
R11, R34: 10k; R_0603_1608Metric
R12, R20: 36.5K; R_0603_1608Metric
R15, R16: 470R; R_0603_1608Metric
R17, R18, R19: 270R; R_0603_1608Metric
SW1: PTS647; SW_SPST_PTS647_Sx38
U1: Argos SMD module; SMD ARGOS
U2: LTC4365DDB; DFN-8-1EP_2x3mm_P0.5mm_EP0.61x2.2mm
U3, U4: TPS63900; WSON-10-1EP_2.5x2.5mm_P0.5mm_EP1.2x2mm

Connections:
+3V3: C1.2, C2.2, C10.1, J3.2, J4.01, J5.1, J6.1, R7.2, R8.2, R11.2, R18.2, U1.30 (VBATT), U1.31 (VDD), U1.32 (VDD), U4.6 (VOUT)
+VCCIO: R17.2; also elsewhere on the board
/LPUART_RX: U1.4 (LPUART_RX); also elsewhere on the board
/LPUART_TX: U1.5 (LPUART_TX); also elsewhere on the board
/RF-BUSY: J7.2, U1.27 (RF-BUSY); also elsewhere on the board
/RF-NRST: J7.3, U1.28 (RF-NRST); also elsewhere on the board
/RF-OUT: C4.1, L1.1, U1.18 (ANT)
/RF-SMA: C6.1, J2.1 (In), L1.2
/RST: C3.2, J4.10, SW1.1, U1.35 (NRST)
/SCL: J3.4, R7.1, U1.34 (SCL)
/SDA: J3.3, R8.1, U1.33 (SDA)
/SPI_CS: J6.6, U1.24 (SPI_CS)
/SPI_MISO: J6.4, U1.22 (SPI_MISO)
/SPI_MOSI: J6.5, U1.2 (SPI_MOSI)
/SPI_SCK: J6.3, U1.3 (SPI_SCK)
/SWCLK: J4.04, U1.25 (SWCLK)
/SWDIO: J4.02, U1.26 (SWDIO)
/SWO: J4.06, U1.23 (SWO)
/UART_RX: J5.3, U1.12 (USART1_RX)
/UART_TX: J5.2, U1.11 (USART1_TX)
/VPA_EN: R9.2, U1.10 (SEL)
/VPA_PGOOD: R10.2, U1.9 (EXTPA_EN)
GND: C1.1, C2.1, C3.1, C4.2, C5.2, C6.2, C7.2, C8.2, C9.2, C10.2, D1.2 (A2), D2.1 (K), D3.1 (K), D4.1 (K), D5.1 (K), D6.1 (K), H1.1, H2.1, H3.1, H4.1 (GND), H5.1, J1.1, J2.2 (Ext), J3.1, J4.03, J4.05, J4.09, J5.4, J6.2, J7.1, R3.1, R12.1, R13.1, R14.1, R20.1, R21.1, R22.1, R34.2, SW1.2, U1.6 (GND), U1.13 (GND), U1.14 (GND), U1.15 (GND), U1.16 (GND), U1.17 (GND), U1.19 (GND), U1.20 (GND), U1.21 (GND), U1.29 (GND), U2.1 (GND), U2.9 (GND), U3.8 (GND), U3.11 (GND), U4.8 (GND), U4.11 (GND); also elsewhere on the board
unnamed: D1.1 (A1), F1.2, J1.2
unnamed: D2.2 (A), R15.1
unnamed: D3.2 (A), R16.1
unnamed: D4.2 (A), R17.1
unnamed: D5.2 (A), R18.1
unnamed: D6.2 (A), R19.1
unnamed: F1.1, Q1.3 (D), R1.2, R4.1, U2.4 (Vin)
unnamed: Q1.1 (G), R6.1
unnamed: Q1.2 (S), Q2.2 (S)
unnamed: Q2.1 (G), R5.2
unnamed: R5.1, R6.2, U2.5 (GATE)
unnamed: R2.1, R3.2, U2.2 (OV)
unnamed: R1.1, R2.2, U2.3 (UV)
unnamed: R4.2, U2.8 (~SHDN)
unnamed: R12.2, U3.3 (CFG1)
unnamed: R13.2, U3.4 (CFG2)
unnamed: R14.2, U3.5 (CFG3)
unnamed: R9.1, R34.1, U3.1 (EN)
unnamed: L2.2, U3.9 (LX1)
unnamed: L2.1, U3.7 (LX2)
unnamed: R10.1, R11.1, U3.2 (SEL)
unnamed: R20.2, U4.3 (CFG1)
unnamed: R21.2, U4.4 (CFG2)
unnamed: R22.2, U4.5 (CFG3)
unnamed: L3.2, U4.9 (LX1)
unnamed: L3.1, U4.7 (LX2)
VBUS: JP1.1 (A), R15.2; also elsewhere on the board
VDD: C7.1, C9.1, JP1.2 (C), U3.10 (VIN), U4.1 (EN), U4.2 (SEL), U4.10 (VIN)
VOUT: C5.1, JP1.3 (B), Q2.3 (D), R16.2, U2.6 (Vout)
VPA: C8.1, R19.2, U1.7 (VDD_EXTPA), U1.8 (VDD_EXTPA), U3.6 (VOUT)

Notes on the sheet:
SPI Optional signals
Shield 3610213126S M3 holes referenced to ground
ARGOS Optional signals
Connecteur N°3
Mechanical and shielding
External Power Amplifier
Serial Wire Debug
Overvoltage, Undervoltage, Reverse, Overcurrent and ESD Input Protection
Connecteur N°1
Connecteur N°2
I²C Optional signals
Supply power 3V3
Buck-boost Converter
Jumper 2.54mm Common 3V3 supply Power amplifier 3V3 supply
Power select
Only ~250mA for 26 dBm uplink for LDA2 Kineis/CNES for all modulation (LDA2, VLDA4, LDK)
Power supply status
Connecteur N°4
Arribada Argos SMD module
LPUART Optional signals
External Supply Protection
ARM Cortex 10pin Debug Connector
Select the 5V power supply from the USB or external connector for the PA power supply and 3V3 for the Argos SMD.
The LTC4365 is configured using an external resistor divider sized according to the manufacturer's recommended topology, providing defined undervoltage and overvoltage thresholds at 2.5 V and 5.0 V respectively. The divider values are calculated assuming an allowable UV pin offset of VOS(UV) = 3 mV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

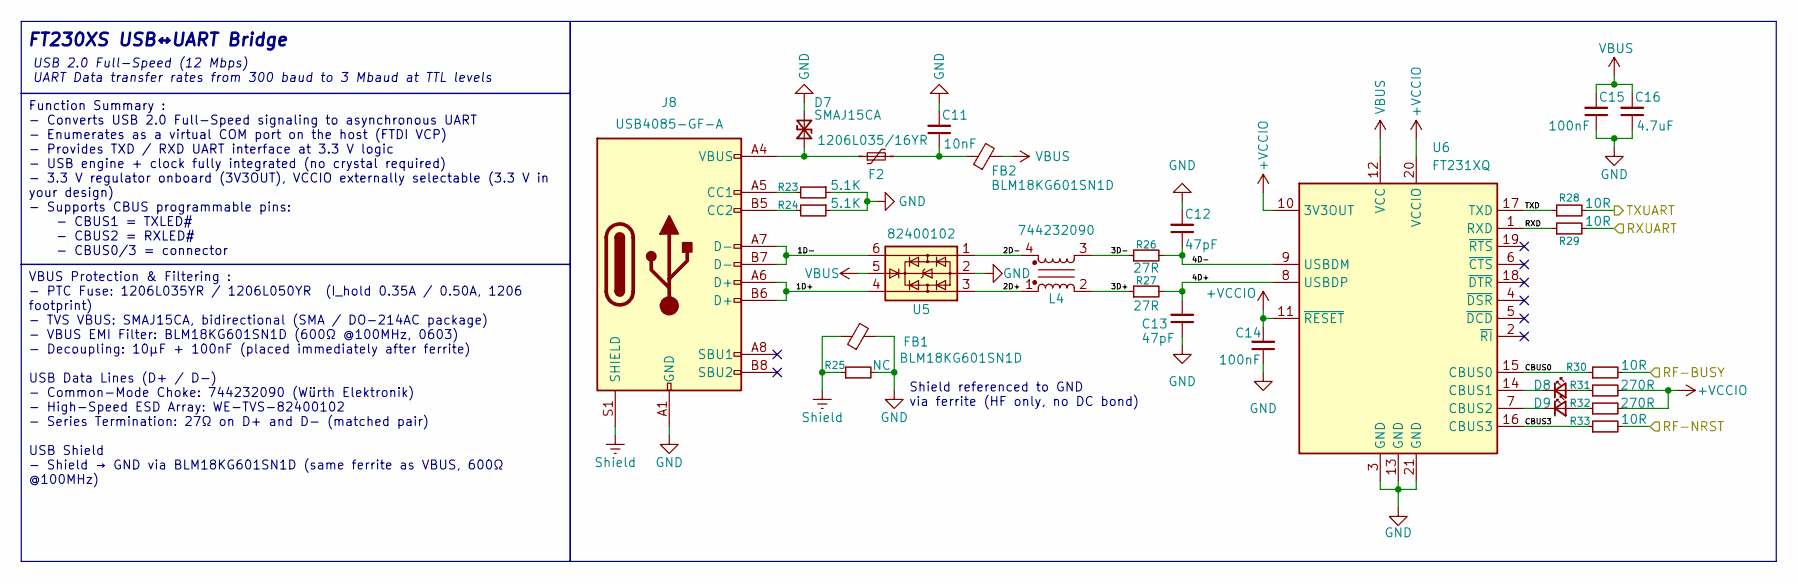
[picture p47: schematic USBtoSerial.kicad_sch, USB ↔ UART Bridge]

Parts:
C11: 10nF; C_0603_1608Metric
C12, C13: 47pF; C_0603_1608Metric
C14, C15: 100nF; C_0603_1608Metric
C16: 4.7uF; C_0603_1608Metric
D7: SMAJ15CA; D_SMA
D8, D9: LED_Small; LED_0603_1608Metric
F2: 1206L035/16YR; Fuse_1206_3216Metric
FB1, FB2: BLM18KG601SN1D; L_0603_1608Metric
J8: USB4085-GF-A; CONN16_USB4085-GF-A_GCT
L4: 744232090; L_CommonMode_Wurth_WE-CNSW-1206
R23, R24: 5.1K; R_0603_1608Metric
R25: NC; R_0603_1608Metric
R26, R27: 27R; R_0603_1608Metric
R28, R29, R30, R33: 10R; R_0603_1608Metric
R31, R32: 270R; R_0603_1608Metric
U5: 82400102; SOT-23-6
U6: FT231XQ; QFN-20-1EP_4x4mm_P0.5mm_EP2.5x2.5mm

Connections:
+VCCIO: C14.2, R31.2, R32.2, U6.10 (3V3OUT), U6.11 (~RESET), U6.20 (VCCIO); also elsewhere on the board
/LPUART_RX: R28.2; also elsewhere on the board
/LPUART_TX: R29.2; also elsewhere on the board
/RF-BUSY: R33.2; also elsewhere on the board
/RF-NRST: R30.2; also elsewhere on the board
/USBtoSerial/1D+: J8.A6 (D+), J8.B6 (D+), U5.4
/USBtoSerial/1D-: J8.A7 (D-), J8.B7 (D-), U5.6
/USBtoSerial/2D+: L4.1, U5.3
/USBtoSerial/2D-: L4.4, U5.1
/USBtoSerial/3D+: L4.2, R27.1
/USBtoSerial/3D-: L4.3, R26.1
/USBtoSerial/4D+: C13.2, R27.2, U6.8 (USBDP)
/USBtoSerial/4D-: C12.1, R26.2, U6.9 (USBDM)
/USBtoSerial/CBUS0: R30.1, U6.15 (CBUS0)
/USBtoSerial/CBUS3: R33.1, U6.16 (CBUS3)
/USBtoSerial/RXD: R29.1, U6.1 (RXD)
/USBtoSerial/TXD: R28.1, U6.17 (TXD)
GND: C11.2, C12.2, C13.1, C14.1, C15.1, C16.1, D7.2 (A2), FB1.2, J8.A1 (GND), J8.A12 (GND), J8.B1 (GND), J8.B12 (GND), R23.1, R24.1, R25.2, U5.2, U6.3 (GND), U6.13 (GND), U6.21 (GND); also elsewhere on the board
unnamed: C11.1, F2.2, FB2.1
unnamed: D7.1 (A1), F2.1, J8.A4 (VBUS), J8.A9 (VBUS), J8.B4 (VBUS), J8.B9 (VBUS)
unnamed: D8.2 (A), R31.1
unnamed: D8.1 (K), U6.14 (CBUS1)
unnamed: D9.2 (A), R32.1
unnamed: D9.1 (K), U6.7 (CBUS2)
unnamed: J8.A5 (CC1), R23.2
unnamed: J8.B5 (CC2), R24.2
Shield: FB1.1, J8.S1 (SHIELD), R25.1
VBUS: C15.2, C16.2, FB2.2, U5.5, U6.12 (VCC); also elsewhere on the board

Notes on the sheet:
USB 2.0 Full-Speed (12 Mbps) UART Data transfer rates from 300 baud to 3 Mbaud at TTL levels
Shield referenced to GND via ferrite (HF only, no DC bond)
FT230XS USB↔UART Bridge
Function Summary : - Converts USB 2.0 Full-Speed signaling to asynchronous UART - Enumerates as a virtual COM port on the host (FTDI VCP) - Provides TXD / RXD UART interface at 3.3 V logic - USB engine + clock fully integrated (no crystal required) - 3.3 V regulator onboard (3V3OUT), VCCIO external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
VBUS Protection & Filtering : - PTC Fuse: 1206L035YR / 1206L050YR (I_hold 0.35A / 0.50A, 1206 footprint) - TVS VBUS: SMAJ15CA, bidirectional (SMA / DO-214AC package) - VBUS EMI Filter: BLM18KG601SN1D (600Ω @100MHz, 0603) - Decoupling: 10µF + 100nF (placed immediately after ferrite) USB Data Lines (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

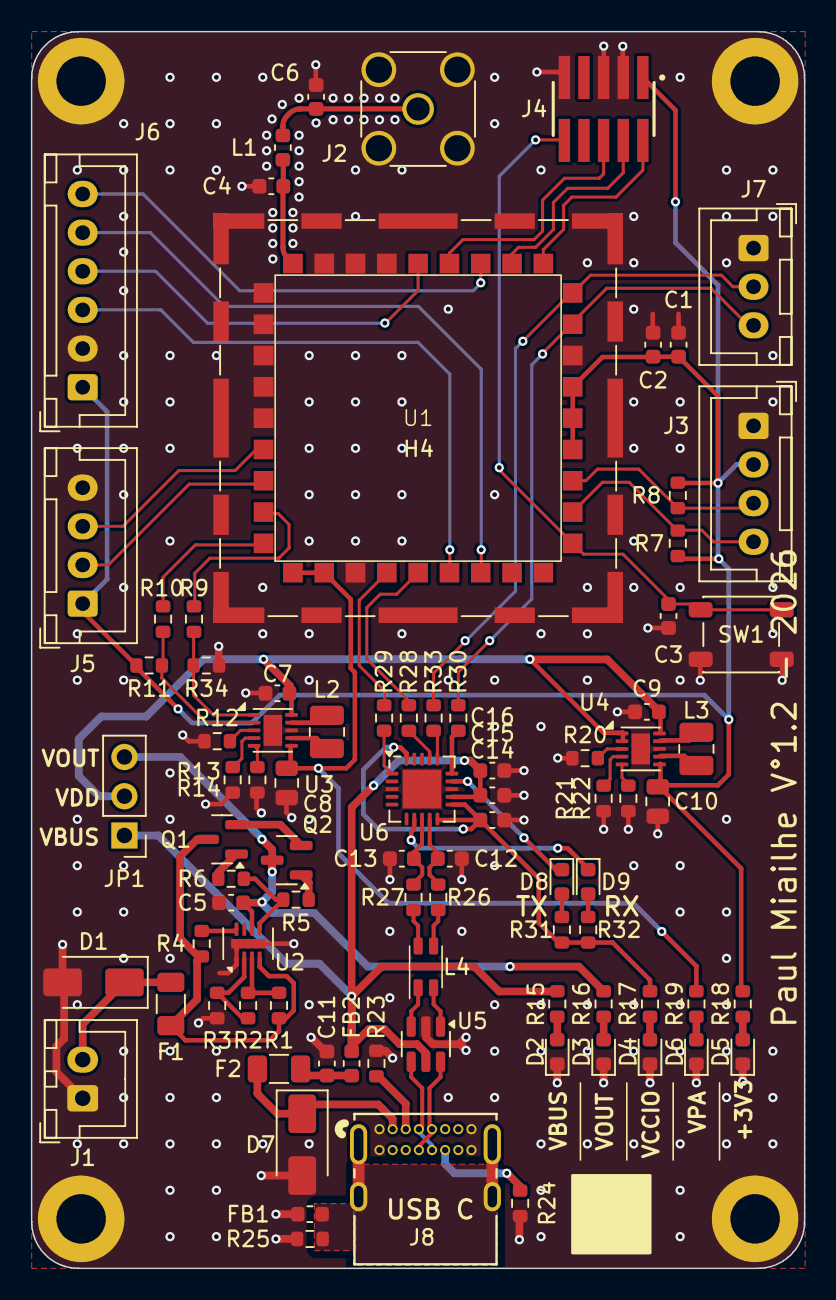
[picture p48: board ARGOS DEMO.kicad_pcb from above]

Board: 4 copper layers, 50.0 x 80.0 mm, 90 parts (0 on the bottom side), 74 nets.

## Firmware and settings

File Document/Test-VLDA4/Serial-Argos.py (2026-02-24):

# -------------------------------------------------------------
# Fichier : Serial-Argos-Demo.py
# Auteur  : Paul Miailhe
# Date    : 21/03/2025
# Objet   : Script de démonstration Argos-SMD ARRIBADA
#
# Copyright (c) 2025 CNES - Centre National d'Études Spatiales 
# -------------------------------------------------------------

"""
Liste complète des commandes AT pour le module SMD Argos (avec tailles approximatives) :

- AT+PING=?                                    : Ping du module SMD                                 (~10 octets)
- AT+FW=?                                      : Lecture de la version firmware                     (~8 octets)
- AT+ADDR=?                                    : Lecture de l'adresse (MAC)                         (~10 octets)
- AT+ADDR=xxxx                                 : Écriture de l'adresse (MAC)                        (~14 octets)
- AT+SECKEY=?                                  : Lecture de la clé secrète                          (~12 octets)
- AT+SECKEY=xxxx                               : Écriture de la clé secrète                         (~38 octets)
- AT+SN=?                                      : Lecture du numéro de série                         (~8 octets)
- AT+ID=?                                      : Lecture de l'identifiant SMD                       (~8 octets)
- AT+ID=xxxx                                   : Écriture de l'identifiant                          (~14 octets)
- AT+TCXO_WU=?                                 : Lecture du temps de warm-up du TCXO                (~14 octets)
- AT+TCXO_WU=xxxx                              : Écriture du temps de warm-up du TCXO               (~20 octets)
- AT+RCONF=?                                   : Lecture de la configuration radio                  (~12 octets)
- AT+SAVE_RCONF=                               : Sauvegarde de la configuration radio               (~16 octets)
- AT+TX=...                                    : Envoi d'un message uplink                          (~58 octets)
- AT+CW=...                                    : Envoi d’un signal en mode onde continue (CW)       (~30 octets)
- AT+LPM=?                                     : Lecture du mode basse consommation                 (~10 octets)
- AT+LPM=...                                   : Écriture du mode basse consommation                (~12 octets)
- AT+VERSION=?                                 : Lecture de la version AT                           (~14 octets)
- AT+UDATE=?                                   : Lecture de la date UTC                             (~12 octets)
- AT+KMAC=0                                    : Réinitialisation de profil KMAC                    (~10 octets)
- AT+KMAC=1                                    : Activation de profil KMAC                          (~10 octets)
- AT+RCONF=44cd3a299068292a74d2126f3402610d    : Configuration radio : LDA2 bande 7                 (~44 octets)
- AT+RCONF=bd176535b394a665bd86f354c5f424fb    : Configuration radio : LDA2L                        (~44 octets)
- AT+RCONF=efd2412f8570581457f2d982e76d44d7    : Configuration radio : VLDA4                        (~44 octets)
- AT+RCONF=41bc11b8980df01ba8b4b8f41099620b    : Configuration radio : LDK                          (~44 octets)
- AT+RCONF=9e51ca0d73594fdb8c3b82d9b799b2b0    : Configuration radio : LDA2 bande 2                 (~44 octets)
"""

import serial
import time
from datetime import datetime

# Configuration du port série
SERIAL_PORT = 'COM4'       # À adapter à votre système
BAUD_RATE = 9600
TIMEOUT = 2   
TX_INTERVAL = 1  # secondes

# Liste des codes d’erreur +ERROR=XX retournés par le module SMD
ERROR_CODES = {
    0:  "Aucune erreur (OK)",
    1:  "Commande AT inconnue",
    2:  "Format de paramètre invalide",
    3:  "Paramètres manquants",
    4:  "Trop de paramètres",
    5:  "Valeur incompatible",
    6:  "Commande AT non reconnue",
    7:  "ID invalide",
    8:  "ID inconnu",
    20: "Longueur des données utilisateur invalide",
    21: "File d'attente de données pleine",
    22: "File d'attente de données vide",
    30: "Timeout de réception RX",
    40: "Erreur transceiver (par ex : message non émis)",
    41: "Erreur d’auto-réglage du transceiver",
    42: "Erreur PLL transceiver",
    43: "Timeout oscillateur transceiver",
    44: "Reset transceiver",
    60: "Fréquence de TX/Modulation non valide dans la config",
}

# Payloads typiques selon les configurations

TXpayload_LDA2 =  "cafebabe0000000000000000000000000000000000000000"

TXpayload =       "000000000000000000000000000000000000000000000000"
TXpayload_LDA2L = "000000000000000000000000000000000000000000000000"
TXpayload_LDK =   "00000000000000000000000000000000000000"
TXpayload_VLDA4 = "000000"

def log_to_file(content):
    with open("argos_log.txt", "a", encoding="utf-8") as f:
        f.write(content + "\n")

def interpret_error(response: str):
    if "+ERROR=" in response:
        try:
            code = int(response.split("+ERROR=")[1].split()[0])
            meaning = ERROR_CODES.get(code, "Code d'erreur inconnu")
            print(f"Erreur détectée : +ERROR={code} → {meaning}")
            log_to_file(f"[ERROR {code}] {meaning}")
        except Exception:
            print("Format d'erreur non reconnu.")
            log_to_file("[ERROR] Format non reconnu")

def timestamp():
    return datetime.now().strftime("%Y-%m-%d %H:%M:%S")

def send_command(ser, command):
    now = timestamp()
    print(f"\n{now} > Envoi : {command}")
    log_to_file(f"[{now}] > {command}")
    ser.write(command.encode() + b'\r\n')
    response = b""
    while True:
        chunk = ser.read(1)
        if not chunk:
            break
        response += chunk
    decoded = response.decode(errors='replace').strip()
    print(f"< Réponse : {decoded}")
    log_to_file(f"[{now}] < {decoded}")
    interpret_error(decoded)
    return decoded

def interactive_mode(ser):
    print("\n Mode interactif activé. Tape une commande AT ou 'exit' pour quitter.")
    while True:
        try:
            user_input = input(">>> ")
            if user_input.lower() in ['exit', 'quit']:
                print("Fin du mode interactif.")
                break
            send_command(ser, user_input)
        except KeyboardInterrupt:
            print("\nInterruption par l'utilisateur.")
            break

def main():
    
    print(f"Démarrage du script : envoi automatique toutes les {TX_INTERVAL} secondes...\n")

    with serial.Serial(SERIAL_PORT, BAUD_RATE, timeout=TIMEOUT) as ser:
        time.sleep(1)

        # send_command(ser, 'AT+PING=?')
        # time.sleep(0.1)
        # send_command(ser, 'AT+FW=?')
        # time.sleep(0.1)
        # send_command(ser, 'AT+ADDR=?')
        # time.sleep(0.1)
        # send_command(ser, 'AT+SN=?')
        # time.sleep(0.1)
        # send_command(ser, 'AT+ID=?')
        # time.sleep(0.1)

        # This section configures the SMD protocol
        send_command(ser, ' ')
        time.sleep(0.1)
        send_command(ser, 'AT+RCONF=?')
        time.sleep(0.1)
        send_command(ser, 'AT+SAVE_RCONF=')
        time.sleep(0.1)
        send_command(ser, 'AT+ADDR=00000029')
        time.sleep(0.1)
        send_command(ser, 'AT+ADDR=?')
        time.sleep(0.1)

        # This section sends two "AT+KMAC" commands to the SMD module to perform a configuration reload.
        send_command(ser, 'AT+KMAC=0')
        time.sleep(0.1)
        send_command(ser, 'AT+KMAC=1')
        time.sleep(0.1)

        # Automatic send loop
        try:
            while True:
                print("\nEnvoi du message Argos...")
                send_command(ser, f"AT+TX={TXpayload_VLDA4}")
                print(f"Attente de {TX_INTERVAL} secondes...\n")
                time.sleep(TX_INTERVAL)

        except KeyboardInterrupt:
            print("⏸Script interrompu. Passage en mode interactif...")
            interactive_mode(ser)

if __name__ == "__main__":
    main()

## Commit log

2026-02-24 Correction USART vers le LPUART
    [ARGOS DEMO.kicad_pcb, ARGOS DEMO.kicad_sch]
2026-02-24 Correction doc
    [ARGOS DEMO.kicad_sch, USBtoSerial.kicad_sch]
2026-02-24 update doc
    [ARGOS DEMO.kicad_pcb]
2026-04-27 Create iBom.html
    Add HTLM Page of Bill of Materials (BOM) listing with the ability to visually correlate and easily search for components and their placements
2026-04-27 feat: Add Argos I-Bom
2026-04-27 feat: Added one section for schematics
2026-04-27 Enhance BOM section with interactive badge
    Added an interactive BOM badge and updated the BOM section.

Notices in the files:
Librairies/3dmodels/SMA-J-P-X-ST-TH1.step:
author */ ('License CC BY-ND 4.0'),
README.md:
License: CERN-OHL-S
